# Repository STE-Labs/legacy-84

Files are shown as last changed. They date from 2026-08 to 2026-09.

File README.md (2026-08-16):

# STE-Labs Legacy 84 Vacuum Tube Amplifier Kits

## Table of Contents
- [Overview](#overview)
- [Simplified Circuit Overview](#simplified-circuit-overview)
- [Features](#features)
- [PCB Specifications](#pcb-specifications)
- [Enclosure Designs](#enclosure-designs)
- [Legacy 84 Mono](#legacy-84-mono)
- [Legacy 84 Mono-Inverted](#legacy-84-mono-inverted)
- [Legacy 84 Stereo](#legacy-84-stereo)
- [Legacy 84 Stereo-Inverted](#legacy-84-stereo-inverted)

## Overview
The Legacy 84 is a series of custom vacuum tube amplifier kits that are available in different configurations. Each configuration is designed to fit into a specific Modushop enclosure. We offer both mono and stereo configurations, with and without inverted tube sockets to enable a wide range of options for builders.

Our kits are designed for enthusiasts who want to build their own high-quality vacuum tube amplifiers. We have optimized our kits against external noise and radiation to ensure the best possible sound quality. Our designs are also optimized for ease of assembly and maintenance. We use high-quality components and materials to ensure durability and reliability.

Special care is taken into the design and routing to ensure that each trace is identical in length and width to maintain signal integrity and reduce noise.

## Simplified Circuit Overview
The Legacy 84 is a fully balanced amplifier design that uses two vacuum tubes for the input stage and two vacuum tubes for the output stage. The input stage is a SRPP/Long Tail Pair configuration, and the output stage is a push-pull configuration. The amplifier is optimized to operate without Global Negative Feedback. Local feedback (cathode degeneration) is used in the input stage to control the gain and reduce distortion. The output stage can be configured with Auto-BIAS or Fixed BIAS.

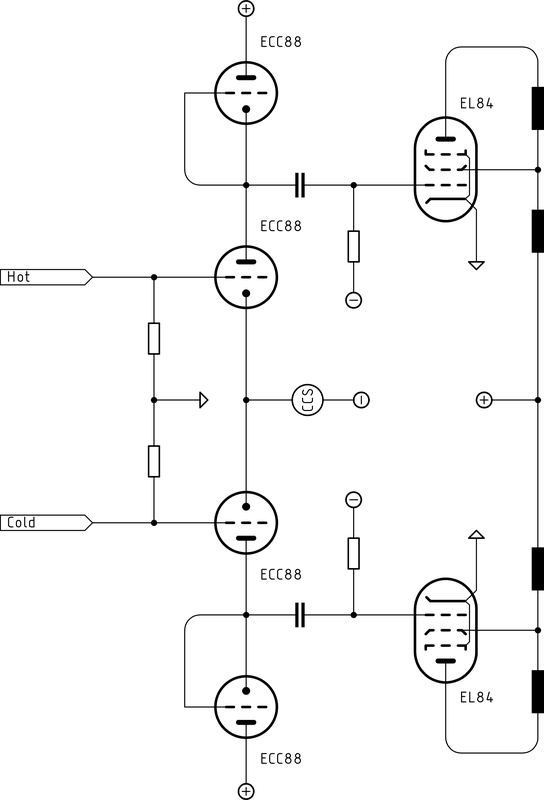
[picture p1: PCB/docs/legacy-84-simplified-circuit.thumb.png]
Legacy 84 Simplified Circuit


|Stage|Compatible Vacuum Tubes|
|---|---|
|Input Stage|6DJ8, E88CC, ECC88, PCC88, 6CG7|
|Output Stage|6BQ5, EL84, EL86|

## Features
- Fully balanced design with support for RCA and XLR inputs
- SRPP/Long Tail Pair input stage
- Push-pull output stage
- Optimized for operation without Global Negative Feedback
- Local feedback (cathode degeneration) in input stage
- Local feedback is switchable between 0dB and 4dB to reduce gain and reduce distortion even further
- Output stage can be configured with Auto-BIAS or Fixed BIAS
- Four Layer PCB Design with integrated RFI/EMI shielding
- Hybrid grounding with star-ground and dedicated ground planes
- "Twisted" trunks for heater connections to reduce electromagnetic interference
- Silicon Carbide (SiC) Rectifier for ultra low noise operation
- Through-hole components for reliability and ease of assembly. No SMD parts are used in our kits.

## PCB Specifications
We provide PCB Kits with the highest possible manufacturing standards. Our Kits are designed to fully comply with regulatory requirements and international safety standards. Our PCBs are manufactured with the thickest possible size and finished with immersion gold (ENIG) to ensure maximum durability and stability.

|Specification|Selection|
|---|---|
|Material|FR4 S1000-2M TG170|
|Thickness|2.4mm|
|Copper Weight (outer layers)|2oz|
|Copper Weight (inner layers)|1oz|
|Solder Mask|Matte black|
|Silkscreen|White|
|Finish|Immersion gold (ENIG)|

## Enclosure Designs
We have pre-designed enclosures for the Legacy 84 kits to make building easier and more accessible. These enclosures are available in different sizes and configurations to suit different needs. You can use our examples directly for your order with Modushop or you can use Front Panel Designer to customize the panels to your own taste.

### Mono Amplifiers
[Modushop Galaxy 2U GX283 & GX288](./Chassis/Galaxy/230/2U/README.md)  
[Modushop Galaxy 3U GX285](./Chassis/Galaxy/230/3U/README.md)  
[Modushop Galaxy 4U GX285](./Chassis/Galaxy/230/4U/README.md)  

### Stereo Amplifiers
[Modushop Slim Line 2U](./Chassis/Slimline/2U/README.md)  
[Modushop Slim Line 3U](./Chassis/Slimline/3U/README.md)  
[Modushop Slim Line 4U](./Chassis/Slimline/4U/README.md)  

[Modushop Galaxy 2U GX383 & GX388](./Chassis/Galaxy/330/2U/README.md)  
[Modushop Galaxy 3U GX385](./Chassis/Galaxy/330/3U/README.md)  
[Modushop Galaxy 4U GX385](./Chassis/Galaxy/330/4U/README.md)  

## Legacy 84 Mono
[View Details](./legacy-84-mono/README.md)

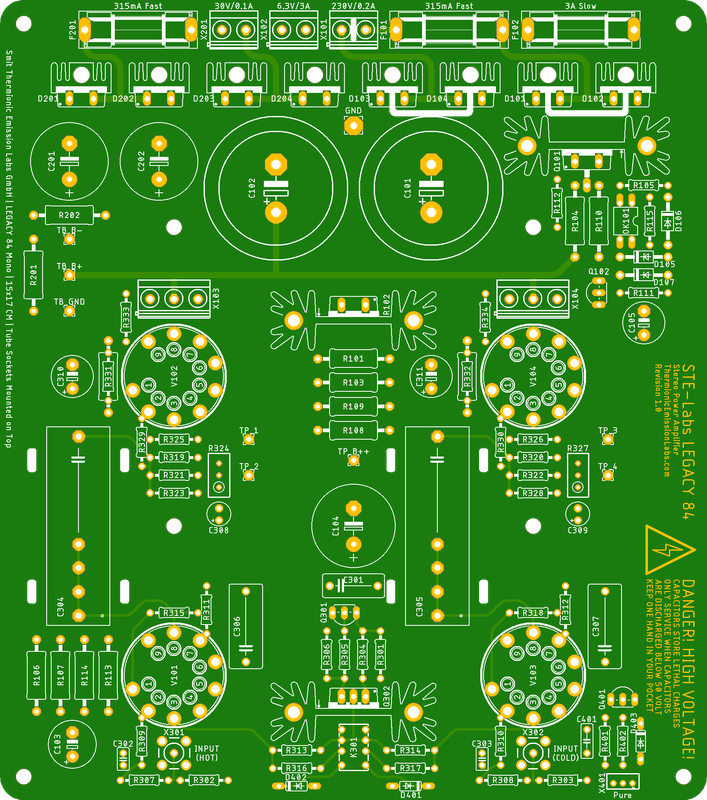
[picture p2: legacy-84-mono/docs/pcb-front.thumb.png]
Legacy 84 Mono


|Dimension|Size|
|---|---|
|Width|150 MM|
|Height|2.4 MM|
|Depth|170 MM|

|Enclosure|
|---|
|[Modushop Galaxy 3U GX285](../Chassis/Galaxy/230/3U/README.md)|
|[Modushop Galaxy 4U GX285](../Chassis/Galaxy/230/4U/README.md)|

## Legacy 84 Mono-Inverted
[View Details](./legacy-84-mono-inverted/README.md)

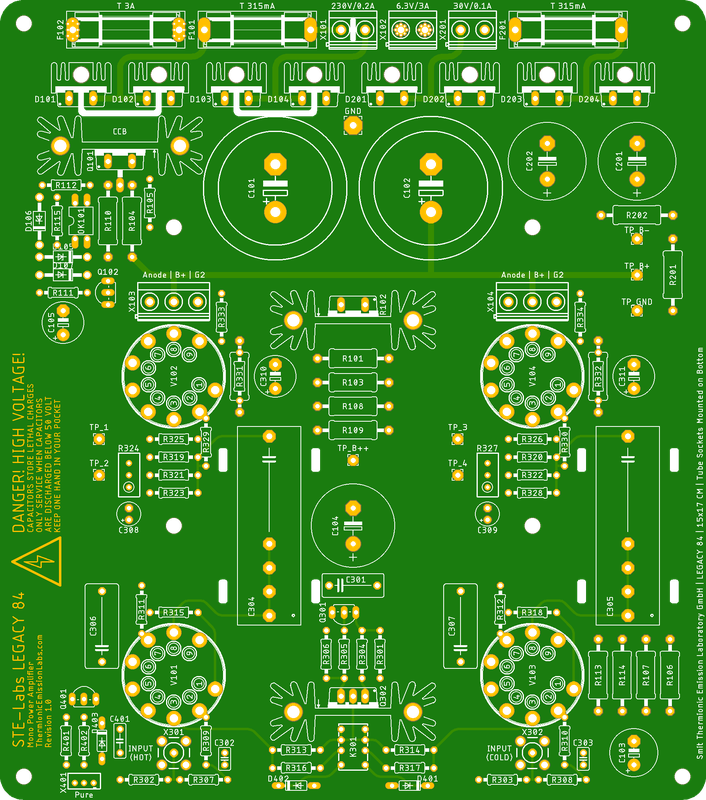
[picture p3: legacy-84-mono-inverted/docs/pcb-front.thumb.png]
Legacy 84 Mono-Inverted


|Dimension|Size|
|---|---|
|Width|170 MM|
|Height|2.4 MM|
|Depth|150 MM|

|Enclosure|
|---|
|[Modushop Galaxy 2U GX283 & GX288](../Chassis/Galaxy/230/2U/README.md)|
|[Modushop Slim Line 2U](../Chassis/Slimline/2U/README.md)|

## Legacy 84 Stereo
[View Details](./legacy-84-stereo/README.md)

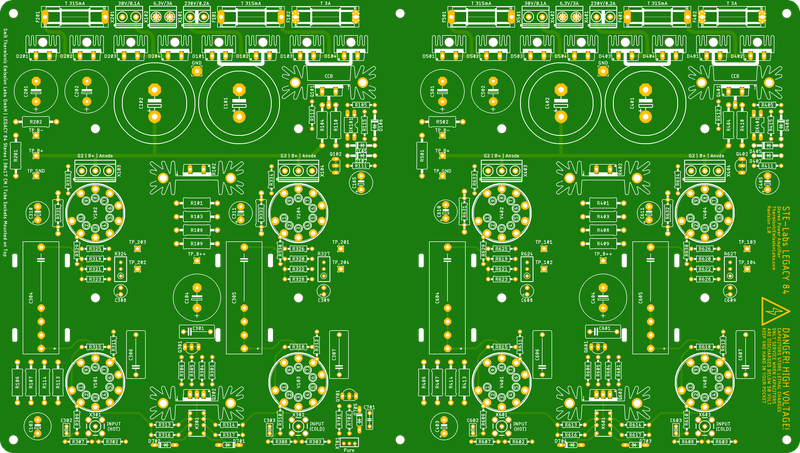
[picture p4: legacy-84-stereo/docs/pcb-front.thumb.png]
Legacy 84 Stereo


|Dimension|Size|
|---|---|
|Width|300 MM|
|Height|2.4 MM|
|Depth|170 MM|

|Enclosure|
|---|
|[Modushop Galaxy 3U GX385](../Chassis/Galaxy/330/3U/README.md)|
|[Modushop Galaxy 4U GX385](../Chassis/Galaxy/330/4U/README.md)|
|[Modushop Slim Line 3U](../Chassis/Slimline/3U/README.md)|
|[Modushop Slim Line 4U](../Chassis/Slimline/4U/README.md)|

## Legacy 84 Stereo-Inverted
[View Details](./legacy-84-stereo-inverted/README.md)

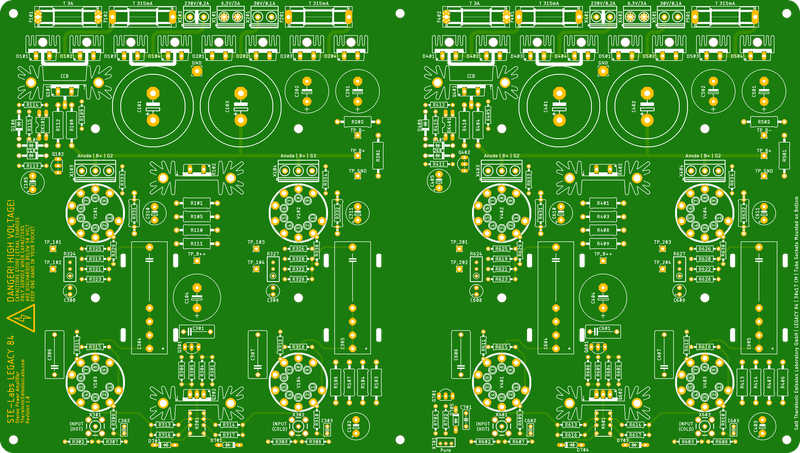
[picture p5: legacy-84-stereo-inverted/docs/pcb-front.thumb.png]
Legacy 84 Stereo-Inverted


|Dimension|Size|
|---|---|
|Width|300 MM|
|Height|2.4 MM|
|Depth|150 MM|

|Enclosure|
|---|
|[Modushop Galaxy 2U GX383 & GX388](../Chassis/Galaxy/330/2U/README.md)|

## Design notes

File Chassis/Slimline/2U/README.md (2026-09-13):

# Modushop Slim Line 2U
These are custom drawings for the **Modushop Slim Line 2U** amplifier enclosures. 
The panel designs are perfectly tailored to fit two of the **Legacy 84 Mono Inverted PCB Kits**.

|Model|Size|Link|PCB|
|-----|----|----|---|
|[Slim Line 02/230 Silver](https://modushop.biz/site/index.php?route=product/product&path=120_246_249&product_id=99)|435 x 230 MM 2U|[https://modushop.biz/site/index.php?route=product/product&path=120_246_249&product_id=97](https://modushop.biz/site/index.php?route=product/product&path=120_246_249&product_id=97)|Legacy 84 Mono Inverted|
|[Slim Line 02/230 Black](https://modushop.biz/site/index.php?route=product/product&path=120_246_249&product_id=100)|435 x 230 MM 2U|[https://modushop.biz/site/index.php?route=product/product&path=120_246_249&product_id=98](https://modushop.biz/site/index.php?route=product/product&path=120_246_249&product_id=98)|Legacy 84 Mono Inverted|
|[Slim Line 02/280 Silver](https://modushop.biz/site/index.php?route=product/product&path=120_246_249&product_id=101)|435 x 280 MM 2U|[https://modushop.biz/site/index.php?route=product/product&path=120_246_249&product_id=99](https://modushop.biz/site/index.php?route=product/product&path=120_246_249&product_id=99)|Legacy 84 Mono Inverted|
|[Slim Line 02/280 Black](https://modushop.biz/site/index.php?route=product/product&path=120_246_249&product_id=102)|435 x 280 MM 2U|[https://modushop.biz/site/index.php?route=product/product&path=120_246_249&product_id=100](https://modushop.biz/site/index.php?route=product/product&path=120_246_249&product_id=100)|Legacy 84 Mono Inverted|

Available at [Modushop.biz](https://modushop.biz/)

## Table of Contents
[Home](../../../README.md)
- [Legacy 84 Mono Inverted](#legacy-84-mono-inverted)
- [Common Panels](#common-panels)
- [Slim Line 02/230](#slim-line-02230)
- [Slim Line 02/280](#slim-line-02280)
- [Additional Kits and Components](#additional-kits-and-components)

## Legacy 84 Mono Inverted
Legacy 84 Mono Inverted PCB Kit

## Common Panels
[Top](#modushop-slim-line-2u)  

### Table of Contents
- [Front Panel](#front-panel)
- [Rear Panel RCA](#rear-panel-rca)
- [Rear Panel XLR](#rear-panel-xlr)

### Front Panel
Modushop Slim Line 2U Front Panel  

### Rear Panel RCA
Modushop Slim Line 2U Rear Panel RCA

### Rear Panel XLR
Modushop Slim Line 2U Rear Panel XLR

## Slim Line 02/230

[Top](#modushop-slim-line-2u)  

### Table of Contents
- [Top Panel](#top-panel-02230)
- [Bottom Panel](#bottom-panel-02230)

### Specifications
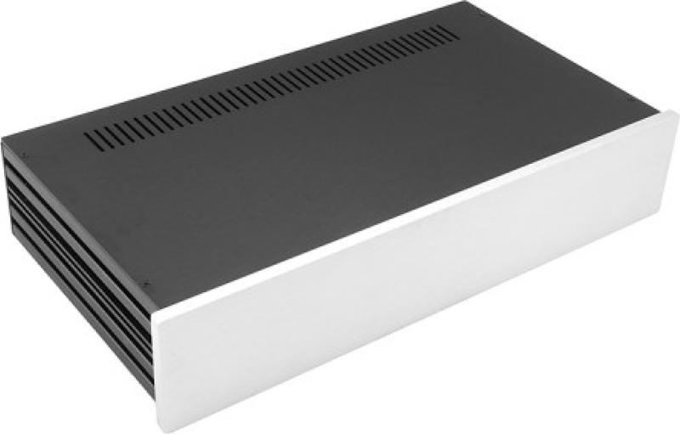
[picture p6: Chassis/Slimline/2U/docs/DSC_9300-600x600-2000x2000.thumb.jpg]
Modushop Slim Line 02/230

|Dimension|Height|Width|Depth|
|---|---|---|---|
|Internal|80|415|230|
|External|86|435|243|
|Faceplate|90|450|10|
|Side Panels|10mm side panels black anodized aluminum|
|Top Cover|3mm black anodized aluminum|
|Bottom Cover|3mm black anodized aluminum|
|Front Panel|10mm black/silver anodized aluminum|
|Rear Panel|3mm black/silver anodized aluminum|

### Top Panel 02/230
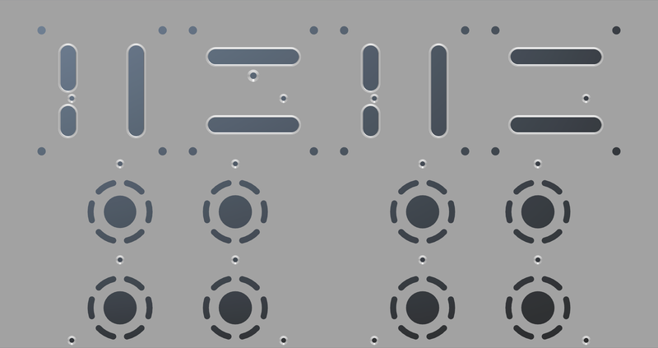
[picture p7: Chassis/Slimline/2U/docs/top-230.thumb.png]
Modushop Slim Line 02/230 Top Panel


### Bottom Panel 02/230
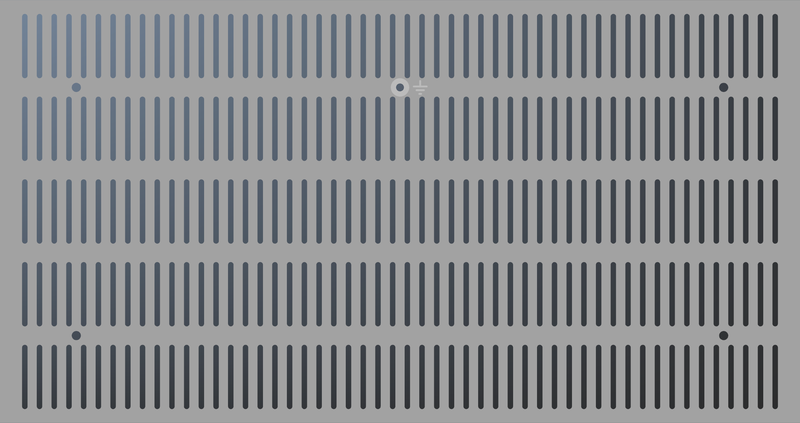
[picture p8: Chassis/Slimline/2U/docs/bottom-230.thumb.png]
Modushop Slim Line 02/230 Bottom Panel


## Slim Line 02/280

[Top](#modushop-slim-line-2u)  

### Table of Contents
- [Top Panel](#top-panel-02280)
- [Bottom Panel](#bottom-panel-02280)

### Specifications
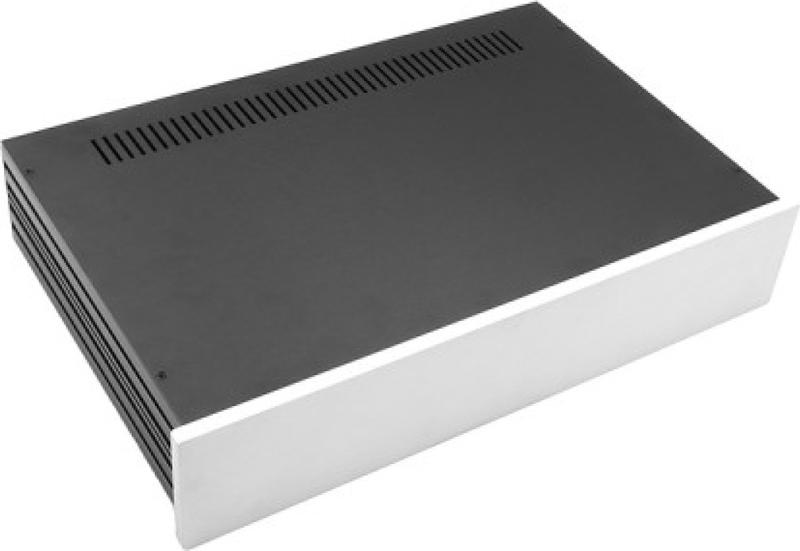
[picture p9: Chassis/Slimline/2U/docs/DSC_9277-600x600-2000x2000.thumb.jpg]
Modushop Slim Line 02/280

|Dimension|Height|Width|Depth|
|---|---|---|---|
|Internal|80|415|280|
|External|86|435|293|
|Faceplate|90|450|10|
|Side Panels|10mm side panels black anodized aluminum|
|Top Cover|3mm black anodized aluminum|
|Bottom Cover|3mm black anodized aluminum|
|Front Panel|10mm black/silver anodized aluminum|
|Rear Panel|3mm black/silver anodized aluminum|

### Top Panel 02/280
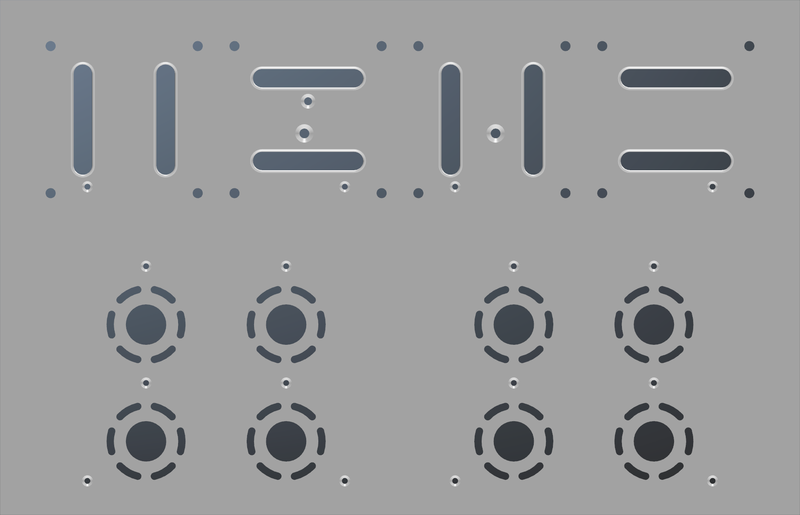
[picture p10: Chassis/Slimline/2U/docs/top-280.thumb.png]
Modushop Slim Line 02/280 Top Panel


### Bottom Panel 02/280
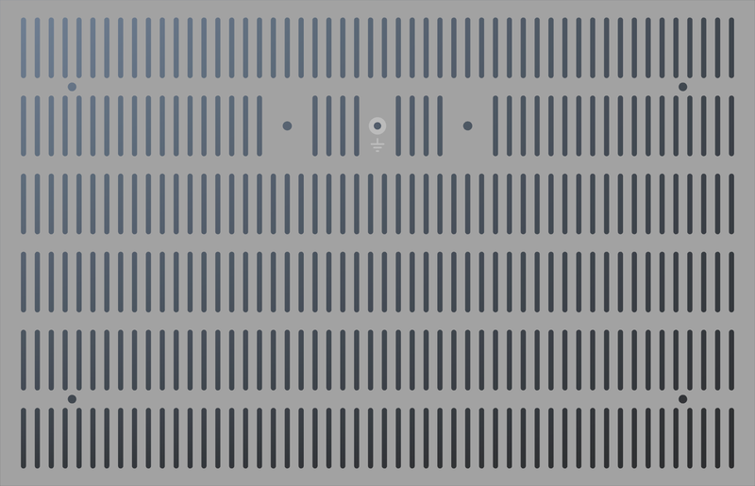
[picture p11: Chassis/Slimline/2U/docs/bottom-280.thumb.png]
Modushop Slim Line 02/280 Bottom Panel


## Additional Kits and Components
[Top](#modushop-slim-line-2u)  

|Item|Description|Product Link|
|----|----|----|
|Legacy 84 Mono Inverted|Legacy 84 Mono Inverted Kit|[Legacy 84 Mono Inverted Kit](../../README.md#legacy-84-mono-inverted)|
|Standby Power Supply|Standby Power Supply Kit|[../../README.md#standby-power-supply](../../README.md#standby-power-supply)|
|IO Shield 2U 6.2 RCA|IO Shield 2U 6.2 RCA|[https://github.com/STE-Labs/io-boards/tree/main/io-board-6-2-rca/README.md](https://github.com/STE-Labs/io-boards/tree/main/io-board-6-2-rca/README.md)|
|IO Shield 2U 6.2 XLR|IO Shield 2U 6.2 XLR|[https://github.com/STE-Labs/io-boards/tree/main/io-board-6-2-xlr/README.md](https://github.com/STE-Labs/io-boards/tree/main/io-board-6-2-xlr/README.md)|
|Anti Vandal Switch|Anti Vandal Switch 16MM with LED|[../../README.md#anti-vandal-switch](../../README.md#anti-vandal-switch)|
|Aluminum Knob 25mm|Aluminum Knob 25mm|[https://modushop.biz/site/index.php?route=product/product&path=312&product_id=755](https://modushop.biz/site/index.php?route=product/product&path=312&product_id=755)|
|Aluminum Knob 40mm|Aluminum Knob 40mm|[https://modushop.biz/site/index.php?route=product/product&path=312&product_id=757](https://modushop.biz/site/index.php?route=product/product&path=312&product_id=757)|
|ECC88|ECC88 Dual Triode|[https://www.jj-electronic.com/en/e88cc-6922-6dj8](https://www.jj-electronic.com/en/e88cc-6922-6dj8)|
|EL84|EL84 Output Pentode|[https://www.jj-electronic.com/en/el84-6bq5](https://www.jj-electronic.com/en/el84-6bq5)|

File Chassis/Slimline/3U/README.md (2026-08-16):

# Modushop Slim Line 3U
Drawings for Custom Amplifier Enclosures

## Table of Contents
[Home](../../../README.md)
- [Common Panels](#common-panels)
- [Slim Line 03/280](#slim-line-03280)
- [Slim Line 03/350](#slim-line-03350)

## Common Panels

[Top](#modushop-slim-line-3u)  

### Table of Contents
- [Front Panel](#front-panel)
- [Rear Panel RCA](#rear-panel-rca)
- [Rear Panel XLR](#rear-panel-xlr)

### Front Panel
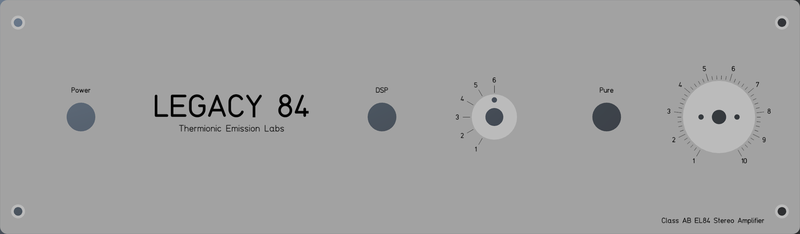
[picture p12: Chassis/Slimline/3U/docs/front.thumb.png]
Modushop Slim Line 2U Front Panel


### Rear Panel RCA
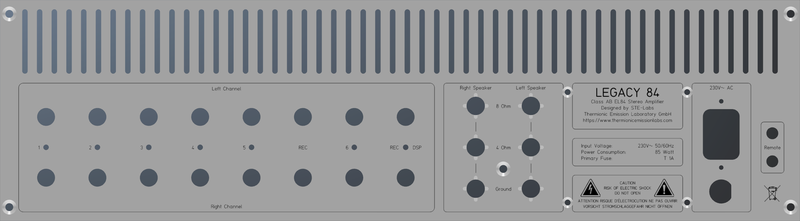
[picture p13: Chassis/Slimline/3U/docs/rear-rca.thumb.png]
Modushop Slim Line 2U Rear Panel RCA


### Rear Panel XLR
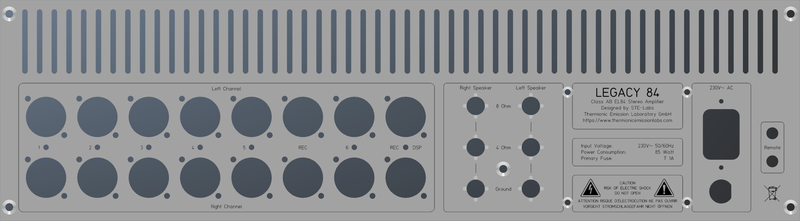
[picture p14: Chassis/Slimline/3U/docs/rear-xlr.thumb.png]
Modushop Slim Line 2U Rear Panel XLR


## Slim Line 03/280

[Top](#modushop-slim-line-3u)  

### Table of Contents
- [Top Panel](#top-panel-03280)
- [Bottom Panel](#bottom-panel-03280)

### Specifications
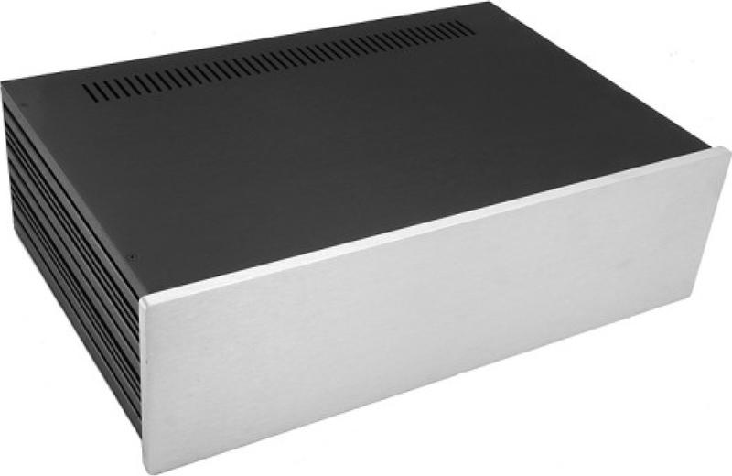
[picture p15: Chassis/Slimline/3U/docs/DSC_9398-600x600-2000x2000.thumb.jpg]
Modushop Slim Line 03/280

|Dimension|Height|Width|Depth|
|---|---|---|---|
|Internal|120|415|280|
|External|126|435|293|
|Faceplate|130|450|10|
|Side Panels|10mm side panels black anodized aluminum|
|Top Cover|3mm black anodized aluminum|
|Bottom Cover|3mm black anodized aluminum|
|Front Panel|10mm black/silver anodized aluminum|
|Rear Panel|3mm black/silver anodized aluminum|

### Top Panel 03/280
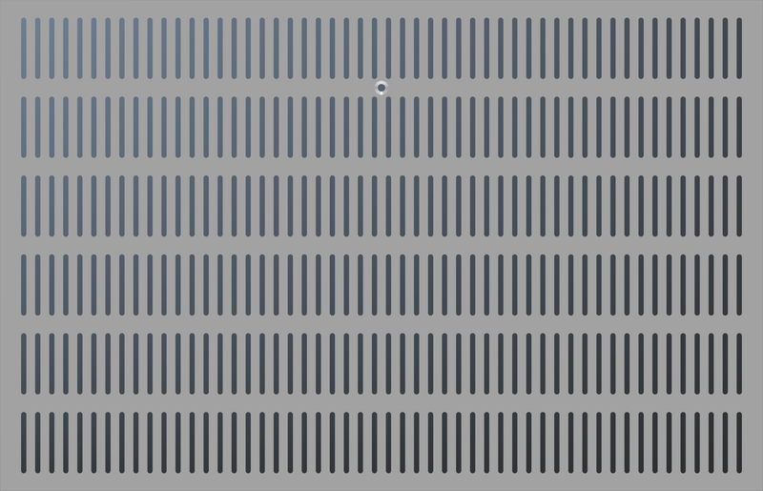
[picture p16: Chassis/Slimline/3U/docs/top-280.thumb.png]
Modushop Slim Line 03/280 Top Panel


### Bottom Panel 03/280
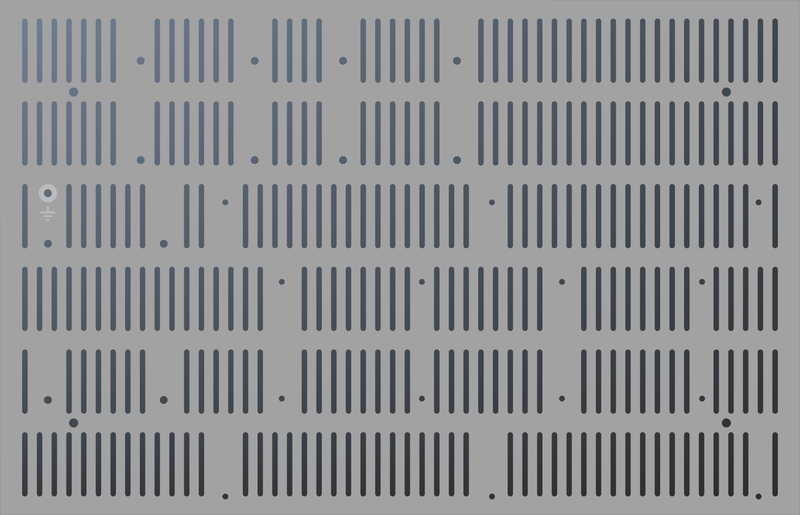
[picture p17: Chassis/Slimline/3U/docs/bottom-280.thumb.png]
Modushop Slim Line 03/280 Bottom Panel


## Slim Line 03/350

[Top](#modushop-slim-line-3u)  

### Table of Contents
- [Top Panel](#top-panel-03350)
- [Bottom Panel](#bottom-panel-03350)

### Specifications
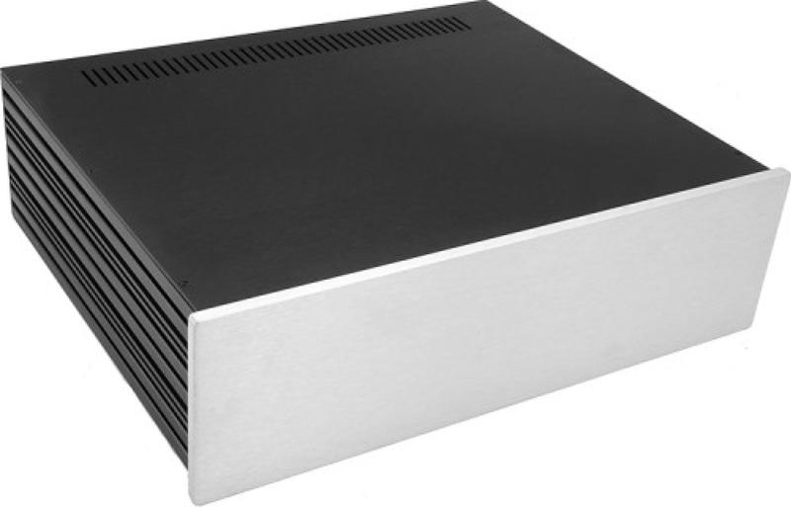
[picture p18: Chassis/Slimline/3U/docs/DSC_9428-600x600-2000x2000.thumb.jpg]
Modushop Slim Line 03/350

|Dimension|Height|Width|Depth|
|---|---|---|---|
|Internal|120|415|350|
|External|126|435|363|
|Faceplate|130|450|10|
|Side Panels|10mm side panels black anodized aluminum|
|Top Cover|3mm black anodized aluminum|
|Bottom Cover|3mm black anodized aluminum|
|Front Panel|10mm black/silver anodized aluminum|
|Rear Panel|3mm black/silver anodized aluminum|

### Top Panel 03/350
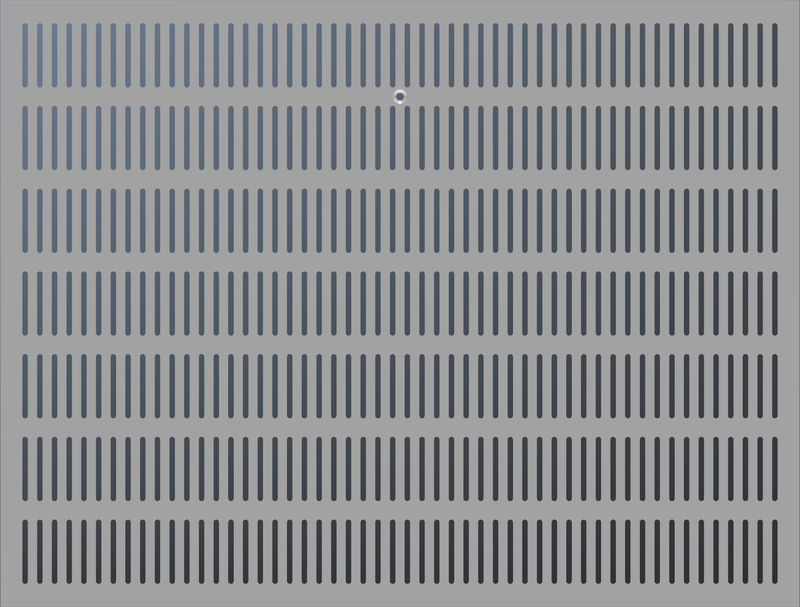
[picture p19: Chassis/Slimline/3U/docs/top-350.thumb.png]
Modushop Slim Line 03/350 Top Panel


### Bottom Panel 03/350
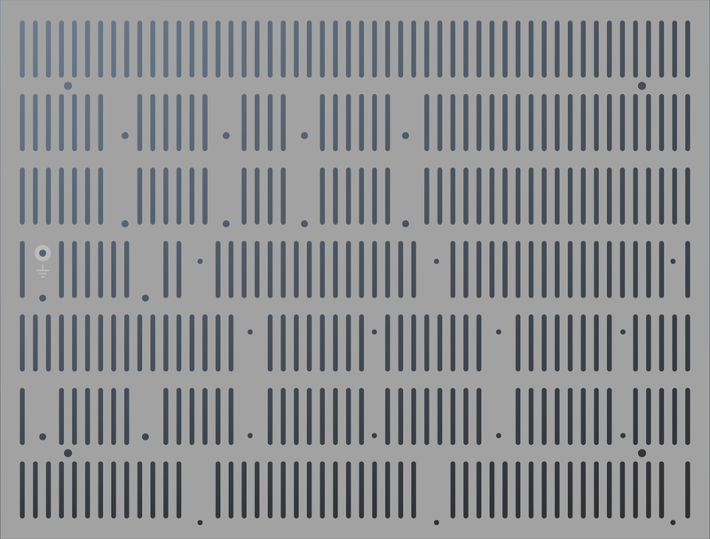
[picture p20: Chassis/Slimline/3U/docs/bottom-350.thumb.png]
Modushop Slim Line 03/350 Bottom Panel


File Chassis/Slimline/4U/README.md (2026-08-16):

# Modushop Slim Line 4U
Drawings for Custom Amplifier Enclosures

## Table of Contents
[Home](../../../README.md)
- [Common Panels](#common-panels)
- [Slim Line 04/280](#slim-line-04280)
- [Slim Line 04/350](#slim-line-04350)

## Common Panels

[Top](#modushop-slim-line-4u)  

### Table of Contents
- [Front Panel](#front-panel)
- [Rear Panel RCA](#rear-panel-rca)
- [Rear Panel XLR](#rear-panel-xlr)

### Front Panel
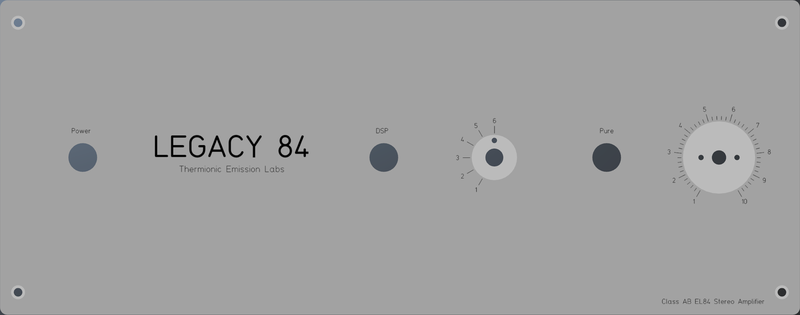
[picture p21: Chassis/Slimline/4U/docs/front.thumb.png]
Modushop Slim Line 2U Front Panel


### Rear Panel RCA
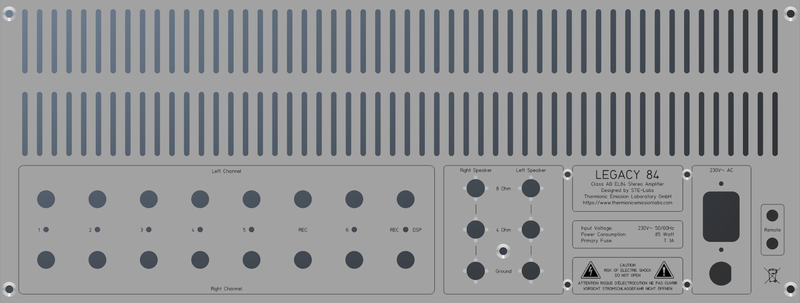
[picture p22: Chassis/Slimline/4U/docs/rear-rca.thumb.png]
Modushop Slim Line 2U Rear Panel RCA


### Rear Panel XLR
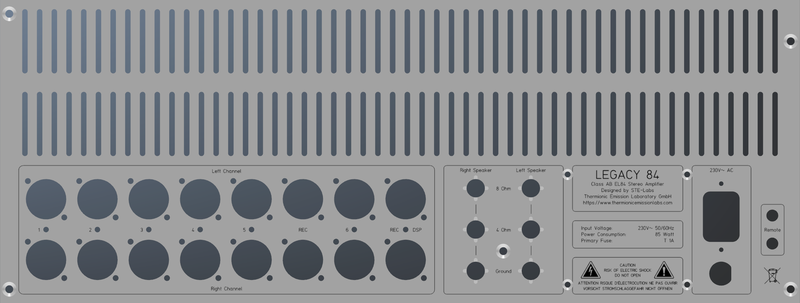
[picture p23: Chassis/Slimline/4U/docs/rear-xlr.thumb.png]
Modushop Slim Line 2U Rear Panel XLR


## Slim Line 04/280

[Top](#modushop-slim-line-4u)  

### Table of Contents
- [Top Panel](#top-panel-04280)
- [Bottom Panel](#bottom-panel-04280)

### Specifications
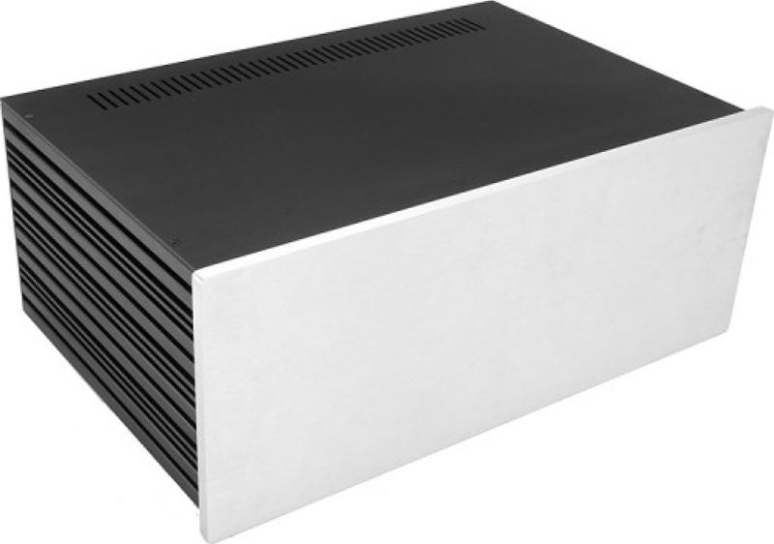
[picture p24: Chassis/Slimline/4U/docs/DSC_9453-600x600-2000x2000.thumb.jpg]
Modushop Slim Line 04/280

|Dimension|Height|Width|Depth|
|---|---|---|---|
|Internal|120|415|280|
|External|126|435|293|
|Faceplate|130|450|10|
|Side Panels|10mm side panels black anodized aluminum|
|Top Cover|3mm black anodized aluminum|
|Bottom Cover|3mm black anodized aluminum|
|Front Panel|10mm black/silver anodized aluminum|
|Rear Panel|3mm black/silver anodized aluminum|

### Top Panel 04/280
Modushop Slim Line 04/280 Top Panel

### Bottom Panel 04/280
Modushop Slim Line 04/280 Bottom Panel

## Slim Line 04/350

[Top](#modushop-slim-line-4u)  

### Table of Contents
- [Top Panel](#top-panel-04350)
- [Bottom Panel](#bottom-panel-04350)

### Specifications
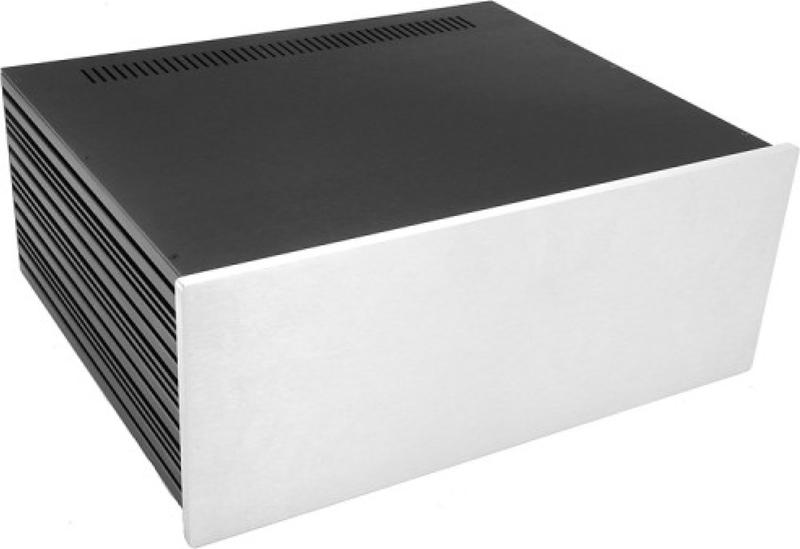
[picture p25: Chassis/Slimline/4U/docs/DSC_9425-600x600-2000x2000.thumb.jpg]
Modushop Slim Line 04/350

|Dimension|Height|Width|Depth|
|---|---|---|---|
|Internal|120|415|350|
|External|126|435|363|
|Faceplate|130|450|10|
|Side Panels|10mm side panels black anodized aluminum|
|Top Cover|3mm black anodized aluminum|
|Bottom Cover|3mm black anodized aluminum|
|Front Panel|10mm black/silver anodized aluminum|
|Rear Panel|3mm black/silver anodized aluminum|

### Top Panel 04/350
Modushop Slim Line 04/350 Top Panel

### Bottom Panel 04/350
Modushop Slim Line 04/350 Bottom Panel

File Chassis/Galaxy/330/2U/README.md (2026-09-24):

# Modushop Galaxy GX383
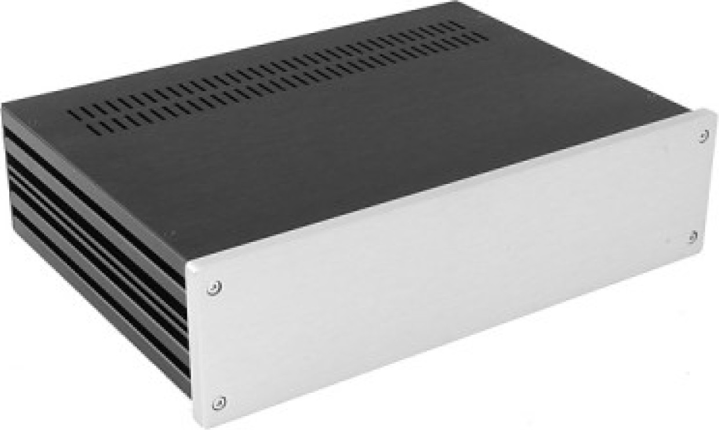
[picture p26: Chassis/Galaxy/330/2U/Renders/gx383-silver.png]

Size: 330 x 230 mm with 10mm front panel

Chose your project
|Name|Description|Inputs|Outputs|
|---|---|---|---|
|[GX383-3-1](./GX383-3-1/README.md)|Drawings for the GX383 with RCA connectors|3|1|
|[GX383-4-0](./GX383-4-0/README.md)|Drawings for the GX383 with RCA connectors|4|0|
|[GX383-4-1](./GX383-4-1/README.md)|Drawings for the GX383 with RCA connectors|4|1|
|[GX383-5-0](./GX383-5-0/README.md)|Drawings for the GX383 with RCA connectors|5|0|

# Modushop Galaxy GX388
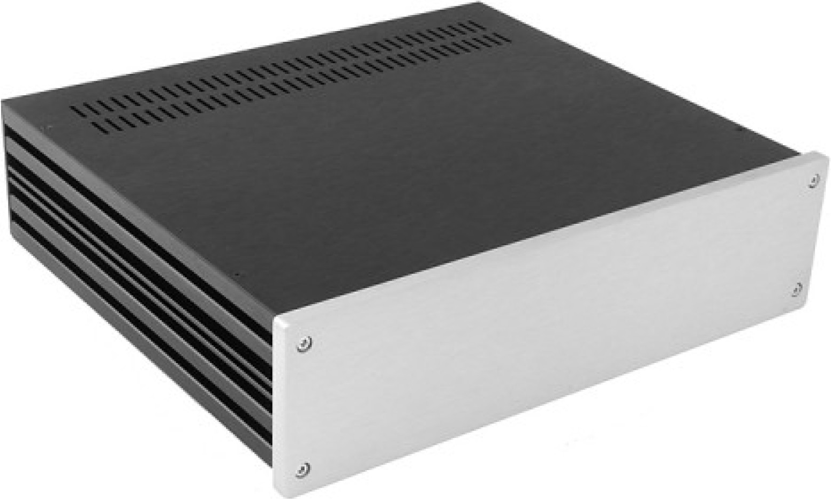
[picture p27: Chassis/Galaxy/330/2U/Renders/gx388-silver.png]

Size: 330 x 280 mm with 10mm front panel

Chose your project
|Name|Description|Inputs|Outputs|
|---|---|---|---|
|[GX388-3-1](./GX388-3-1/README.md)|Drawings for the GX388 with RCA connectors|3|1|
|[GX388-4-0](./GX388-4-0/README.md)|Drawings for the GX388 with RCA connectors|4|0|
|[GX388-4-1](./GX388-4-1/README.md)|Drawings for the GX388 with RCA connectors|4|1|
|[GX388-5-0](./GX388-5-0/README.md)|Drawings for the GX388 with RCA connectors|5|0|

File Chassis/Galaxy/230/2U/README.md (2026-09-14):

# Modushop Galaxy 230 2U
[Home](../../../README.md)

These are custom drawings for the **Modushop Galaxy 2U** amplifier enclosures. 
The panel designs are perfectly tailored to fit the **Legacy 84 Mono Inverted PCB Kit**.

|Model|Size|Link|PCB|
|-----|----|----|---|
|[Galaxy 2U GX283 Silver](https://modushop.biz/site/index.php?route=product/product&path=25_291_293&product_id=439)|230 x 230 MM 2U|[https://modushop.biz/site/index.php?route=product/product&path=25_291_293&product_id=439](https://modushop.biz/site/index.php?route=product/product&path=25_291_293&product_id=439)|Legacy 84 Mono Inverted|
|[Galaxy 2U GX283 Black](https://modushop.biz/site/index.php?route=product/product&path=25_291_293&product_id=440)|230 x 230 MM 2U|[https://modushop.biz/site/index.php?route=product/product&path=25_291_293&product_id=440](https://modushop.biz/site/index.php?route=product/product&path=25_291_293&product_id=440)|Legacy 84 Mono Inverted|
|[Galaxy 2U GX288 Silver](https://modushop.biz/site/index.php?route=product/product&path=25_291_293&product_id=443)|230 x 280 MM 2U|[https://modushop.biz/site/index.php?route=product/product&path=25_291_293&product_id=443](https://modushop.biz/site/index.php?route=product/product&path=25_291_293&product_id=443)|Legacy 84 Mono Inverted|
|[Galaxy 2U GX288 Black](https://modushop.biz/site/index.php?route=product/product&path=25_291_293&product_id=444)|230 x 280 MM 2U|[https://modushop.biz/site/index.php?route=product/product&path=25_291_293&product_id=444](https://modushop.biz/site/index.php?route=product/product&path=25_291_293&product_id=444)|Legacy 84 Mono Inverted|

Available at [Modushop.biz](https://modushop.biz/)

## Table of Contents
- [Legacy 84 Mono Inverted](#legacy-84-mono-inverted)
- [Common Panels](#common-panels)
- [Galaxy GX283](#galaxy-gx283)
- [Galaxy GX288](#galaxy-gx288)

## Legacy 84 Mono Inverted
Legacy 84 Mono Inverted PCB Kit

## Common Panels
[Top](#modushop-galaxy-230-2u)  
These panels are shared between all Galaxy 2U models.

#### Front Panel
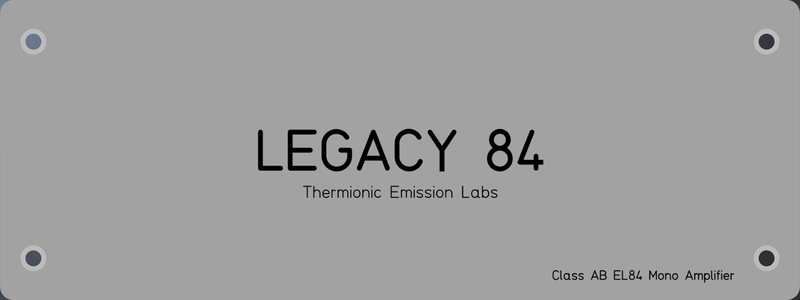
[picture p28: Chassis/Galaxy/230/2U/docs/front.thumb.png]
Modushop Galaxy 2U Front Panel


#### Rear Panel RCA
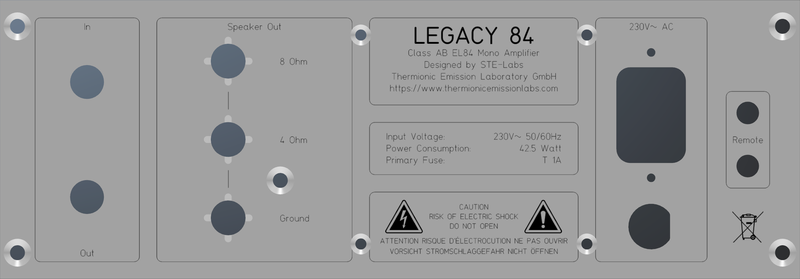
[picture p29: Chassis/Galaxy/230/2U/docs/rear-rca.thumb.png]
Modushop Galaxy 2U Rear Panel


#### Rear Panel XLR
Modushop Galaxy 2U Rear Panel

## Galaxy GX283
[Top](#modushop-galaxy-230-2u)

### Table of Contents
- [Top Panel](#top-panel-gx283)
- [Bottom Panel](#bottom-panel-gx283)

### Specifications
Galaxy GX283

### Top Panel GX283
Modushop Galaxy GX283 Top Panel

### Bottom Panel GX283
Modushop Galaxy GX283 Bottom Panel

## Galaxy GX288
[Top](#modushop-galaxy-230-2u)

### Table of Contents
- [Top Panel](#top-panel-gx288)
- [Bottom Panel](#bottom-panel-gx288)

### Specifications
Galaxy GX288

### Top Panel GX288
Modushop Galaxy GX288 Top Panel

### Bottom Panel GX288
Modushop Galaxy GX288 Bottom Panel

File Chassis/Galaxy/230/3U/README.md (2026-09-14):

# Modushop Galaxy 230 3U
[Home](../../../README.md)  

These are custom drawings for the **Modushop Galaxy 3U** amplifier enclosures. 
The panel designs are perfectly tailored to fit the **Legacy 84 Mono PCB Kit**.

|Model|Size|Link|PCB|
|-----|----|----|---|
|[Galaxy 3U GX288 Silver](https://modushop.biz/site/index.php?route=product/product&path=30_295_298&product_id=632)|230 x 280 MM 3U|[https://modushop.biz/site/index.php?route=product/product&path=30_295_298&product_id=632](https://modushop.biz/site/index.php?route=product/product&path=30_295_298&product_id=632)|Legacy 84 Mono|
|[Galaxy 3U GX288 Black](https://modushop.biz/site/index.php?route=product/product&path=30_295_298&product_id=633)|230 x 280 MM 3U|[https://modushop.biz/site/index.php?route=product/product&path=30_295_298&product_id=633](https://modushop.biz/site/index.php?route=product/product&path=30_295_298&product_id=633)|Legacy 84 Mono|
|[Galaxy 3U GX285 Silver](https://modushop.biz/site/index.php?route=product/product&path=30_295_298&product_id=628)|230 x 350 MM 3U|[https://modushop.biz/site/index.php?route=product/product&path=30_295_298&product_id=628](https://modushop.biz/site/index.php?route=product/product&path=30_295_298&product_id=628)|Legacy 84 Mono|
|[Galaxy 3U GX285 Black](https://modushop.biz/site/index.php?route=product/product&path=30_295_298&product_id=629)|230 x 350 MM 3U|[https://modushop.biz/site/index.php?route=product/product&path=30_295_298&product_id=629](https://modushop.biz/site/index.php?route=product/product&path=30_295_298&product_id=629)|Legacy 84 Mono|

Available at [Modushop.biz](https://modushop.biz/)

## Table of Contents
- [Legacy 84 Mono](#legacy-84-mono)
- [Common Panels](#common-panels)
- [Galaxy GX288](#galaxy-gx288)
- [Galaxy GX285](#galaxy-gx285)

## Legacy 84 Mono
Legacy 84 Mono PCB Kit

## Common Panels
[Top](#modushop-galaxy-330-3u)  
These panels are shared between all Galaxy 3U models.

#### Front Panel
Modushop Galaxy 2U Front Panel

#### Rear Panel RCA
Modushop Galaxy 2U Rear Panel RCA

#### Rear Panel XLR
Modushop Galaxy 2U Rear Panel XLR

## Galaxy GX288
[Top](#modushop-galaxy-330-3u)  

### Table of Contents
- [Top Panel](#top-panel-gx288)
- [Bottom Panel](#bottom-panel-gx288)

### Specifications
Galaxy GX288

### Top Panel GX288
Modushop Galaxy GX288 Top Panel

### Bottom Panel GX288
Modushop Galaxy GX288 Bottom Panel

## Galaxy GX285
[Top](#modushop-galaxy-330-3u)  

### Table of Contents
- [Top Panel](#top-panel-gx285)
- [Bottom Panel](#bottom-panel-gx285)

### Specifications
Galaxy GX285

### Top Panel GX285
Modushop Galaxy GX285 Top Panel

### Bottom Panel GX285
Modushop Galaxy GX285 Bottom Panel

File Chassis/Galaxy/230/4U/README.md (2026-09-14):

# Modushop Galaxy 230 4U
[Home](../../../README.md)  

These are custom drawings for the **Modushop Galaxy 4U** amplifier enclosures. 
The panel designs are perfectly tailored to fit the **Legacy 84 Mono PCB Kit**.

|Model|Size|Link|PCB|
|-----|----|----|---|
|[Galaxy 4U GX288 Silver](https://modushop.biz/site/index.php?route=product/product&path=31_300_302&product_id=634)|230 x 280 MM 4U|[https://modushop.biz/site/index.php?route=product/product&path=31_300_302&product_id=634](https://modushop.biz/site/index.php?route=product/product&path=31_300_302&product_id=634)|Legacy 84 Mono|
|[Galaxy 4U GX288 Black](https://modushop.biz/site/index.php?route=product/product&path=31_300_303&product_id=635)|230 x 280 MM 4U|[https://modushop.biz/site/index.php?route=product/product&path=31_300_303&product_id=635](https://modushop.biz/site/index.php?route=product/product&path=31_300_303&product_id=635)|Legacy 84 Mono|
|[Galaxy 4U GX285 Silver](https://modushop.biz/site/index.php?route=product/product&path=31_300_302&product_id=631)|230 x 350 MM 4U|[https://modushop.biz/site/index.php?route=product/product&path=31_300_302&product_id=631](https://modushop.biz/site/index.php?route=product/product&path=31_300_302&product_id=631)|Legacy 84 Mono|
|[Galaxy 4U GX285 Black](https://modushop.biz/site/index.php?route=product/product&path=31_300_303&product_id=630)|230 x 350 MM 4U|[https://modushop.biz/site/index.php?route=product/product&path=31_300_303&product_id=630](https://modushop.biz/site/index.php?route=product/product&path=31_300_303&product_id=630)|Legacy 84 Mono|

Available at [Modushop.biz](https://modushop.biz/)

## Table of Contents
- [Legacy 84 Mono](#legacy-84-mono)
- [Common Panels](#common-panels)
- [Galaxy GX288](#galaxy-gx288)
- [Galaxy GX285](#galaxy-gx285)

## Legacy 84 Mono
Legacy 84 Mono PCB Kit

## Common Panels
[Top](#modushop-galaxy-330-4u)  
These panels are shared between all Galaxy 4U models.

#### Front Panel
Modushop Galaxy 2U Front Panel

#### Rear Panel RCA
Modushop Galaxy 2U Rear Panel

#### Rear Panel XLR
Modushop Galaxy 2U Rear Panel

## Galaxy GX288

[Top](#modushop-galaxy-330-4u)  
### Table of Contents
- [Top Panel](#top-panel-gx288)
- [Bottom Panel](#bottom-panel-gx288)

### Specifications
Galaxy GX288

### Top Panel GX288
Modushop Galaxy GX288 Top Panel

### Bottom Panel GX288
Modushop Galaxy GX288 Bottom Panel

## Galaxy GX285

[Top](#modushop-galaxy-330-4u)  

### Table of Contents
- [Top Panel](#top-panel-gx285)
- [Bottom Panel](#bottom-panel-gx285)

### Specifications
Galaxy GX285

### Top Panel GX285
Modushop Galaxy GX285 Top Panel

### Bottom Panel GX285
Modushop Galaxy GX285 Bottom Panel

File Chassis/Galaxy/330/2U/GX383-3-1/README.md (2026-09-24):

# Modushop GX383 with three inputs and one output


Here you can find an overview with the source files needed for a customized GX383 chassis from Modushop.
Use the URLs in this document to ensure that you select the proper chassis and customization options.

## Front Panel Designer Files
All the files provided here are example files that have been fully tested for compatability with the [Legacy 84](https://thermionicemissionlabs.com/products/legacy/84-stereo-inverted) and the [Impact 84]((https://thermionicemissionlabs.com/products/impact/84-stereo-inverted)). You are free to modify these drawings to your own liking. We do not provide support for these drawings, nor do we validate them if you modify them. Please notify Modushop if you have modified our drawings so they can validate your changes and ensure that they can manufacture the panels for you.

Keep these limitations in mind in modify the drawings:
- The minimum radius for a corner is 2mm
- Rounded bezels are not possible

You can download a free copy of Front Panel Designer [here](https://www.frontpanelexpress.com/front-panel-designer).

### Templates for Customized Panels
Download complete panel templates [here](https://github.com/STE-Labs/legacy-84/releases/download/latest/Galaxy-330-2U-GX383-3-1.zip)...

|Description|URL|Example|
|---|---|---|
|Front Panel|[front.fpd](./front.fpd)|[front-3-1.png](../Renders/front-3-1.png)|
|Rear Panel|[rear-rca.fpd](./rear-rca.fpd)|[rear-rca-3-1.png](../Renders/rear-3-1-rca.png)|
|Top Panel|[top.fpd](./top.fpd)|[gx383-top.png](../Renders/gx383-top.png)|
|Bottom Panel*|[bottom.fpd](./bottom.fpd)|[gx383-bottom.png](../Renders/gx383-bottom.png)|

\* Alternatively you can make use of Modushop's Fully vented aluminium cover instead of using a customized panel for the bottom. This will safe you the costs for customization, however you will have to drill your own holes for the feet and for the grounding post. You can find the Fully vented aluminium cover [here](https://modushop.biz/site/index.php?route=product/product&product_id=589).

## GX383 Chassis
|Description|URL|Color|
|---|---|---|
|GX383 Chassis|https://modushop.biz/site/index.php?route=product/product&product_id=445|Silver|
|GX383 Chassis|https://modushop.biz/site/index.php?route=product/product&product_id=446|Black|

## Customization Options
|Description|URL|Option|Amount|
|---|---|---|---|
|Drilling panel 2/3/4mm|https://modushop.biz/site/index.php?route=product/product&product_id=490|More than 40 holes|3x|
|Drilling front panel 10mm|https://modushop.biz/site/index.php?route=product/product&product_id=489|Customized on front/rear part of the panel|1x|
|Digital Printing|https://modushop.biz/site/index.php?route=product/product&product_id=579||2x|

## Optional Parts
Order these optional parts to complete your Amplifier.
|Description|URL|Amount|
|---|---|---|
|Anti-Vibration Feet|https://modushop.biz/site/index.php?route=product/category&path=313|1x|
|Aluminium knob 24.5 mm|https://modushop.biz/site/index.php?route=product/product&path=312&product_id=755|1x|
|Aluminium knob 39.5 mm|https://modushop.biz/site/index.php?route=product/product&path=312&product_id=757|1x|

## How to order
1. Create an account with [Modushop](https://modushop.biz/) if you are not yet already registered.
2. Select the chassis that you want and add it to your shopping cart.
3. Find the customization options and add them to your shopping cart.
4. Add the optional parts to your shopping cart.
5. Checkout your shopping cart. You will receive an order ID and payment instructions.
6. Send an email with the FPD files attached to info@modushop.biz. Mention your order ID in the email so Modushop can link it to your order.
7. Modushop will process your order for a custom chassis once the payment has been processed. 

# Transformers
The drawings that are provided here make use of customized transformers from [Automatic Electric Europe](https://www.aeetransformers.com/) (AEE). Both the Legacy 84 and the Impact 84 use the exact same transformers.

You can order the transformers by sending an [email](info@ae-europe.nl) to AEE. Send them the name of the product that you are building (Legacy 84 or Impact 84) so they have context and use the lookup table below for the correct part numbers
|Description|Part number|Amount|
|---|---|---|
|Power Transformer 230V primary*|15236-POT|1x|
|Power Transformer 110V primary*|15236-POT-US|1x|
|Output transformer EL84 Pushpull 10k primary|15237-POT|2x|

\* Only order the Power Transformer that is suitable for your mains voltage.

### Example email
```
To: info@ae-europe.nl  
Subject: Transformers for Legacy 84 Stereo amplifier kit  
Message:  
Dear AEE,  

I have ordered the STE-Labs Legacy 84 Stereo amplifier kit together with a customized enclosure from Modushop. I would like to order the complementary transformers with you. My build requires these transformers:  
- 1x 15236-POT  
- 2x 15237-POT  

Best regards,  
Builder
```

# PCB Kits
We supply all the internal PCBs that you need to build a full amplifier. If you want a perfect build experience then we advice you to order these PCB-kits with us:
|Name|Description|URL|
|---|---|---|
|Legacy 84 Stereo Inverted|Legacy 84 Amplifier PCB with inverted tube sockets||
|Impact 84 Stereo Inverted|Impact 84 Direct Coupled Amplifier PCB with inverted tube sockets||
|IO Board 3:1|IO Board with three inputs and one output with DSP support||
|Power Supply 1|Standby Power Supply with remote switch board||
|GX383-DSP|Complementary kit to complete your build||

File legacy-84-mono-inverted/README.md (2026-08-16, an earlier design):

# Legacy 84 Mono Inverted

## Table of Contents
[Home](../README.md)
- [PCB](#PCB)
  - [PCB Front Side](#PCB-Front-Side)
  - [PCB Back Side](#PCB-Back-Side)
- [Circuit Diagram](#circuit-diagram)
  - [Power Supply](#power-supply)
  - [Negative Power Supply](#negative-power-supply)
  - [Amplifier](#amplifier)
  - [Pure Switch](#pure-switch)
- [Chassis Examples](#chassis-examples)
  - [Modushop Slim Line 2U 230mm](#modushop-slim-line-3u-230mm)
    - [Front Panel](#modushop-slim-line-2u-front-panel)
    - [Back Panel](#modushop-slim-line-2u-back-panel)
    - [Top Panel](#modushop-slim-line-2u-top-panel)
    - [Bottom Panel](#modushop-slim-line-2u-bottom-panel)
  - [Modushop Slim Line 2U 280mm](#modushop-slim-line-2u-280mm)
    - [Front Panel](#modushop-slim-line-2u-front-panel)
    - [Back Panel](#modushop-slim-line-2u-back-panel)
    - [Top Panel](#modushop-slim-line-2u-top-panel)
    - [Bottom Panel](#modushop-slim-line-2u-bottom-panel)
- [Bill of Materials](#bill-of-materials)

## PCB
### PCB Front Side
PCB Front

### PCB Back Side
PCB Back

## Circuit Diagram
### Power Supply
Circuit Diagram Power Supply</br>
[High Resolution](./docs/circuit-diagram-power-supply.png)</br>
[PDF](./docs/circuit-diagram-power-supply.pdf)</br>

### Negative Power Supply
Circuit Diagram Negative Power Supply</br>
[High Resolution](./docs/circuit-diagram-negative-power-supply.png)</br>
[PDF](./docs/circuit-diagram-negative-power-supply.pdf)</br>

### Amplifier
Circuit Diagram Amplifier</br>
[High Resolution](./docs/circuit-diagram-amplifier.png)</br>
[PDF](./docs/circuit-diagram-amplifier.pdf)</br>

### Pure Switch
Circuit Diagram Pure Switch</br>
[High Resolution](./docs/circuit-diagram-pure-switch.png)</br>
[PDF](./docs/circuit-diagram-pure-switch.pdf)</br>

## Chassis Examples
### Modushop Galaxy 2U 230mm

### Modushop Galaxy 2U 280mm

### Modushop Slim Line 2U 230mm
Slim Line 2U/230 Silver</br>
[Slim Line 2U/230 Silver](https://modushop.biz/site/index.php?route=product/product&path=120_246_249&product_id=97)</br></br>
Slim Line 2U/230 Black</br>
[Slim Line 2U/230 Black](https://modushop.biz/site/index.php?route=product/product&path=120_246_249&product_id=98)</br>

|Panel|File|
|---|---|
|Front|[Slim Line 2U Front](../Chassis/Slimline/2U/Front.fpd)|
|Rear RCA|[Slim Line 2U Rear RCA](../Chassis/Slimline/2U/Rear-RCA.fpd)|
|Rear XLR|[Slim Line 2U Rear XLR](../Chassis/Slimline/2U/Rear-XLR.fpd)|
|Top|[Slim Line 2U Top 230](../Chassis/Slimline/2U/230/Top.fpd)|
|Bottom|[Slim Line 2U Bottom 230](../Chassis/Slimline/2U/230/Bottom.fpd)|

#### Front Panel
Modushop Slim Line 2U Front Panel</br>
#### Back Panel RCA
Modushop Slim Line 2U Back Panel RCA</br>
#### Back Panel XLR
Modushop Slim Line 2U Back Panel XLR</br>
#### Top Panel
Modushop Slim Line 2U Top Panel 230mm</br>
#### Bottom Panel
Modushop Slim Line 2U Bottom Panel 230mm</br>

### Modushop Slim Line 2U 280mm
Slim Line 2U/280 Silver</br>
[Slim Line 2U/280 Silver](https://modushop.biz/site/index.php?route=product/product&path=120_246_249&product_id=99)</br></br>
Slim Line 2U/280 Black</br>
[Slim Line 2U/280 Black](https://modushop.biz/site/index.php?route=product/product&path=120_246_249&product_id=100)</br>

|Panel|File|
|---|---|
|Front|[Slim Line 2U Front](../Chassis/Slimline/2U/Front.fpd)|
|Rear RCA|[Slim Line 2U Rear RCA](../Chassis/Slimline/2U/Rear-RCA.fpd)|
|Rear XLR|[Slim Line 2U Rear XLR](../Chassis/Slimline/2U/Rear-XLR.fpd)|
|Top|[Slim Line 2U Top 280](../Chassis/Slimline/2U/280/Top.fpd)|
|Bottom|[Slim Line 2U Bottom 280](../Chassis/Slimline/2U/280/Bottom.fpd)|

#### Front Panel
Modushop Slim Line 2U Front Panel</br>
#### Back Panel RCA
Modushop Slim Line 2U Back Panel RCA</br>
#### Back Panel XLR
Modushop Slim Line 2U Back Panel XLR</br>
#### Top Panel
Modushop Slim Line 2U Top Panel 280mm</br>
#### Bottom Panel
Modushop Slim Line 2U Bottom Panel 280mm</br>

## Bill of Materials

- [ ] 2x 100 Resistor
- [ ] 3x 100/2W Resistor
- [ ] 1x 100/35W Resistor
- [ ] 7x 100k Resistor
- [ ] 1x 100k Resistor (2W)
- [ ] 2x 100k Trimm Resistor
- [ ] 1x 100k/2W Resistor
- [ ] 1x 100n Capacitor
- [ ] 2x 100n/400V Capacitor
- [ ] 1x 100nF Capacitor
- [ ] 1x 100u/100V Polarized Capacitor
- [ ] 2x 100uF/25V Polarized Capacitor
- [ ] 2x 10_270/2W Cathode Resistor
- [ ] 3x 10k Resistor
- [ ] 2x 110 Resistor
- [ ] 2x 1M Resistor
- [ ] 1x 1N4148 Diode
- [ ] 7x 1k Resistor
- [ ] 2x 1u/400V Coupling Capacitor
- [ ] 2x 1u/50V Polarized Capacitor
- [ ] 2x 2.2k/2W Resistor
- [ ] 2x 2.7k Resistor
- [ ] 1x 2.7k/2W Resistor
- [ ] 1x 22 Resistor
- [ ] 1x 220u/16V Polarized Capacitor
- [ ] 2x 220u/450V Polarized Capacitor
- [ ] 2x 22p Capacitor
- [ ] 1x 270k/2W Resistor
- [ ] 2x 27k Resistor
- [ ] 1x 30 Resistor
- [ ] 2x 4.7k Resistor
- [ ] 5x 470 Resistor
- [ ] 2x 470k/2W Resistor
- [ ] 2x 470u/100V Polarized Capacitor
- [ ] 1x 47k/2W Resistor
- [ ] 1x 47u/450V Polarized Capacitor
- [ ] 1x B3B-ZR Connector
- [ ] 1x BC547 NPN Transistor
- [ ] 1x BS170 N-Channel MOS FET
- [ ] 1x BZX55C15 Z Diode
- [ ] 1x BZX55C2V7 Z Diode
- [ ] 2x BZX55C5V1 Z Diode
- [ ] 8x C3D03060A Diode
- [ ] 2x ECC88 Valve
- [ ] 2x EL84 Valve
- [ ] 1x G6K-2P-Y Relay
- [ ] 2x IRF820 N-Channel MOS FET
- [ ] 3x MKDSN1,5/2-5,08 Terminal Block
- [ ] 2x MKDSN1,5/3-5,08 Terminal Block
- [ ] 1x MPSA42 Transistor
- [ ] 1x PC817 Opto Coupler
- [ ] 3x SK104-PAD Heatsink
- [ ] 8x SK95-2M3 Heatsink
- [ ] 2x ST-SMB-V SMB Connector
- [ ] 2x T 315mA Fuse Holder
- [ ] 1x T3A Fuse Holder
- [ ] 1x UF4003 Diode

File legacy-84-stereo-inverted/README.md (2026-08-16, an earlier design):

# Legacy 84 Stereo Inverted

## Table of Contents
[Home](../README.md)
- [PCB](#pcb)
  - [PCB Front Side](#pcb-front-side)
  - [PCB Back Side](#pcb-back-side)
- [Circuit Diagram Left Channel](#circuit-diagram-left-channel)
  - [Power Supply](#power-supply)
  - [Negative Power Supply](#negative-power-supply)
  - [Amplifier](#amplifier)
- [Circuit Diagram Right Channel](#circuit-diagram-right-channel)
  - [Power Supply](#power-supply-1)
  - [Negative Power Supply](#negative-power-supply-1)
  - [Amplifier](#amplifier-1)
- [Circuit Diagram Pure Switch](#circuit-diagram-pure-switch)
- [Chassis Examples](#chassis-examples)
  - [Modushop Galaxy 2U GX383 & GX388](#modushop-galaxy-2u-gx383--gx388)
- [Bill of Materials](#bill-of-materials)

## PCB
### PCB Front Side
PCB Front

### PCB Back Side
PCB Back

## Circuit Diagram Left Channel
### Power Supply
Circuit Diagram Left Channel Power Supply</br>
[High Resolution](./docs/circuit-diagram-left-channel-power-supply.png)</br>
[PDF](./docs/circuit-diagram-left-channel-power-supply.pdf)</br>

### Negative Power Supply
Circuit Diagram Left Channel Negative Power Supply</br>
[High Resolution](./docs/circuit-diagram-left-channel-negative-power-supply.png)</br>
[PDF](./docs/circuit-diagram-left-channel-negative-power-supply.pdf)</br>

### Amplifier
Circuit Diagram Left Channel Amplifier</br>
[High Resolution](./docs/circuit-diagram-left-channel-amplifier.png)</br>
[PDF](./docs/circuit-diagram-left-channel-amplifier.pdf)</br>

## Circuit Diagram Right Channel
### Power Supply
Circuit Diagram Right Channel Power Supply</br>
[High Resolution](./docs/circuit-diagram-right-channel-power-supply.png)</br>
[PDF](./docs/circuit-diagram-right-channel-power-supply.pdf)</br>

### Negative Power Supply
Circuit Diagram Right Channel Negative Power Supply</br>
[High Resolution](./docs/circuit-diagram-right-channel-negative-power-supply.png)</br>
[PDF](./docs/circuit-diagram-right-channel-negative-power-supply.pdf)</br>

### Amplifier
Circuit Diagram Right Channel Amplifier</br>
[High Resolution](./docs/circuit-diagram-right-channel-amplifier.png)</br>
[PDF](./docs/circuit-diagram-right-channel-amplifier.pdf)</br>

## Circuit Diagram Pure Switch
Circuit Diagram Pure Switch</br>
[High Resolution](./docs/circuit-diagram-pure-switch.png)</br>
[PDF](./docs/circuit-diagram-pure-switch.pdf)</br>

## Chassis Examples
### Modushop Galaxy 2U GX383 & GX388
Panel drawings for the Legacy 84 Stereo Inverted in a Galaxy 2U enclosure.

[View Chassis Details](../Chassis/Galaxy/330/2U/README.md)

## Bill of Materials

- [ ] 4x 100 Resistor
- [ ] 6x 100/2W Resistor
- [ ] 2x 100/35W Resistor
- [ ] 14x 100k Resistor
- [ ] 2x 100k Resistor (2W)
- [ ] 4x 100k Trimm Resistor
- [ ] 2x 100k/2W Resistor
- [ ] 2x 100n Capacitor
- [ ] 4x 100n/400V Capacitor
- [ ] 1x 100nF Capacitor
- [ ] 2x 100u/100V Polarized Capacitor
- [ ] 4x 100u/25V Polarized Capacitor
- [ ] 4x 10_270/2W Cathode Resistor
- [ ] 5x 10k Resistor
- [ ] 4x 110 Resistor
- [ ] 4x 1M Resistor
- [ ] 2x 1N4148 Diode
- [ ] 11x 1k Resistor
- [ ] 4x 1u/400V Coupling Capacitor
- [ ] 4x 1u/50V Polarized Capacitor
- [ ] 4x 2.2k/2W Resistor
- [ ] 6x 2.7k Resistor
- [ ] 2x 2.7k/2W Resistor
- [ ] 2x 22 Resistor
- [ ] 2x 220u/16V Polarized Capacitor
- [ ] 4x 220u/450V Polarized Capacitor
- [ ] 4x 22p Capacitor
- [ ] 2x 270k/2W Resistor
- [ ] 4x 27k Resistor
- [ ] 2x 30 Resistor
- [ ] 4x 4.7k Resistor
- [ ] 10x 470 Resistor
- [ ] 4x 470k/2W Resistor
- [ ] 4x 470u/100V Polarized Capacitor
- [ ] 2x 47k/2W Resistor
- [ ] 2x 47u/450V Polarized Capacitor
- [ ] 1x B3B-ZR Connector
- [ ] 2x BC547 NPN Transistor
- [ ] 1x BS170 N-Channel MOS FET
- [ ] 2x BZX55C15 Z Diode
- [ ] 2x BZX55C2V7 Z Diode
- [ ] 2x BZX55C5V1 Z Diode (DO41Z10)
- [ ] 1x BZX55C5V1 Z Diode (DO35-7)
- [ ] 16x C3D03060A Diode
- [ ] 4x ECC88 Valve
- [ ] 4x EL84 Valve
- [ ] 2x G6K-2P-Y Relay
- [ ] 4x IRF820 N-Channel MOS FET
- [ ] 6x MKDSN1,5/2-5,08 Terminal Block
- [ ] 4x MKDSN1,5/3-5,08 Terminal Block
- [ ] 2x MPSA42 Transistor
- [ ] 2x PC817 Opto Coupler
- [ ] 6x SK104-PAD Heatsink
- [ ] 16x SK95-2M3 Heatsink
- [ ] 4x ST-SMB-V SMB Connector
- [ ] 4x T250mA Fuse Holder
- [ ] 2x T2A Fuse Holder
- [ ] 2x UF4003 Diode

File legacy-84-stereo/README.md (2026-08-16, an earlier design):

# Legacy 84 Stereo

## Table of Contents
[Home](../README.md)
- [PCB](#PCB)
  - [PCB Front Side](#PCB-Front-Side)
  - [PCB Back Side](#PCB-Back-Side)
- [Circuit Diagram Left Channel](#circuit-diagram-left-channel)
  - [Power Supply](#power-supply)
  - [Negative Power Supply](#negative-power-supply)
  - [Amplifier](#amplifier)
- [Circuit Diagram Right Channel](#circuit-diagram-right-channel)
  - [Power Supply](#power-supply-1)
  - [Negative Power Supply](#negative-power-supply-1)
  - [Amplifier](#amplifier-1)
- [Circuit Diagram Pure Switch](#circuit-diagram-pure-switch)
- [Chassis Examples](#chassis-examples)
  - [Modushop Slim Line 3U 280mm](#modushop-slim-line-3u-280mm)
    - [Front Panel](#modushop-slim-line-3u-front-panel)
    - [Back Panel](#modushop-slim-line-3u-back-panel)
    - [Top Panel](#modushop-slim-line-3u-top-panel)
    - [Bottom Panel](#modushop-slim-line-3u-bottom-panel)
  - [Modushop Slim Line 3U 350mm](#modushop-slim-line-3u-350mm)
    - [Front Panel](#modushop-slim-line-3u-front-panel)
    - [Back Panel](#modushop-slim-line-3u-back-panel)
    - [Top Panel](#modushop-slim-line-3u-top-panel)
    - [Bottom Panel](#modushop-slim-line-3u-bottom-panel)
  - [Modushop Slim Line 4U 280mm](#modushop-slim-line-4u-280mm)
    - [Front Panel](#modushop-slim-line-4u-front-panel)
    - [Back Panel](#modushop-slim-line-4u-back-panel)
    - [Top Panel](#modushop-slim-line-4u-top-panel)
    - [Bottom Panel](#modushop-slim-line-4u-bottom-panel)
  - [Modushop Slim Line 4U 350mm](#modushop-slim-line-4u-350mm)
    - [Front Panel](#modushop-slim-line-4u-front-panel)
    - [Back Panel](#modushop-slim-line-4u-back-panel)
    - [Top Panel](#modushop-slim-line-4u-top-panel)
    - [Bottom Panel](#modushop-slim-line-4u-bottom-panel)
- [Bill of Materials](#bill-of-materials)

## PCB
### PCB Front Side
PCB Front

### PCB Back Side
PCB Back

## Circuit Diagram Left Channel
### Power Supply
Circuit Diagram Left Channel Power Supply</br>
[High Resolution](./docs/circuit-diagram-left-channel-power-supply.png)</br>
[PDF](./docs/circuit-diagram-left-channel-power-supply.pdf)</br>

### Negative Power Supply
Circuit Diagram Left Channel Negative Power Supply</br>
[High Resolution](./docs/circuit-diagram-left-channel-negative-power-supply.png)</br>
[PDF](./docs/circuit-diagram-left-channel-negative-power-supply.pdf)</br>

### Amplifier
Circuit Diagram Left Channel Amplifier</br>
[High Resolution](./docs/circuit-diagram-left-channel.png)</br>
[PDF](./docs/circuit-diagram-left-channel.pdf)</br>

## Circuit Diagram Right Channel
### Power Supply
Circuit Diagram Right Channel Power Supply</br>
[High Resolution](./docs/circuit-diagram-right-channel-power-supply.png)</br>
[PDF](./docs/circuit-diagram-right-channel-power-supply.pdf)</br>

### Negative Power Supply
Circuit Diagram Right Channel Negative Power Supply</br>
[High Resolution](./docs/circuit-diagram-right-channel-negative-power-supply.png)</br>
[PDF](./docs/circuit-diagram-right-channel-negative-power-supply.pdf)</br>

### Amplifier
Circuit Diagram Right Channel Amplifier</br>
[High Resolution](./docs/circuit-diagram-right-channel.png)</br>
[PDF](./docs/circuit-diagram-right-channel.pdf)</br>

## Circuit Diagram Pure Switch
Circuit Diagram Pure Switch</br>
[High Resolution](./docs/circuit-diagram-pure-switch.png)</br>
[PDF](./docs/circuit-diagram-pure-switch.pdf)</br>

## Chassis Examples
### Modushop Slim Line 3U 280mm
Slim Line 3U/280 Silver</br>
[Slim Line 3U/280 Silver](https://modushop.biz/site/index.php?route=product/product&path=118_251_253&product_id=125)</br></br>
Slim Line 3U/280 Black</br>
[Slim Line 3U/280 Black](https://modushop.biz/site/index.php?route=product/product&path=118_251_253&product_id=126)</br>

|Panel|File|
|---|---|
|Front|[Slim Line 3U Front](../Chassis/Slimline/3U/Front.fpd)|
|Rear RCA|[Slim Line 3U Rear RCA](../Chassis/Slimline/3U/Rear-RCA.fpd)|
|Rear XLR|[Slim Line 3U Rear XLR](../Chassis/Slimline/3U/Rear-XLR.fpd)|
|Top|[Slim Line 3U Top 280](../Chassis/Slimline/3U/280/Top.fpd)|
|Bottom|[Slim Line 3U Bottom 280](../Chassis/Slimline/3U/280/Bottom.fpd)|

#### Front Panel
Modushop Slim Line 3U Front Panel</br>
#### Back Panel RCA
Modushop Slim Line 3U Back Panel RCA</br>
#### Back Panel XLR
Modushop Slim Line 3U Back Panel XLR</br>
#### Top Panel
Modushop Slim Line 3U Top Panel 280mm</br>
#### Bottom Panel
Modushop Slim Line 3U Bottom Panel 280mm</br>

### Modushop Slim Line 3U 350mm
Slim Line 3U/350 Silver</br>
[Slim Line 3U/350 Silver](https://modushop.biz/site/index.php?route=product/product&path=118_251_253&product_id=127)</br></br>
Slim Line 3U/350 Black</br>
[Slim Line 3U/350 Black](https://modushop.biz/site/index.php?route=product/product&path=118_251_253&product_id=128)</br>

|Panel|File|
|---|---|
|Front|[Slim Line 3U Front](../Chassis/Slimline/3U/Front.fpd)|
|Rear RCA|[Slim Line 3U Rear RCA](../Chassis/Slimline/3U/Rear-RCA.fpd)|
|Rear XLR|[Slim Line 3U Rear XLR](../Chassis/Slimline/3U/Rear-XLR.fpd)|
|Top|[Slim Line 3U Top 350](../Chassis/Slimline/3U/350/Top.fpd)|
|Bottom|[Slim Line 3U Bottom 350](../Chassis/Slimline/3U/350/Bottom.fpd)|

#### Front Panel
Modushop Slim Line 3U Front Panel</br>
#### Back Panel RCA
Modushop Slim Line 3U Back Panel RCA</br>
#### Back Panel XLR
Modushop Slim Line 3U Back Panel XLR</br>
#### Top Panel
Modushop Slim Line 3U Top Panel 350mm</br>
#### Bottom Panel
Modushop Slim Line 3U Bottom Panel 350mm</br>

### Modushop Slim Line 4U 280mm
Slim Line 4U/280 Silver</br>
[Slim Line 4U/280 Silver](https://modushop.biz/site/index.php?route=product/product&path=121_255_257&product_id=149)</br></br>
Slim Line 4U/280 Black</br>
[Slim Line 4U/280 Black](https://modushop.biz/site/index.php?route=product/product&path=121_255_257&product_id=150)</br>

|Panel|File|
|---|---|
|Front|[Slim Line 4U Front](../Chassis/Slimline/4U/Front.fpd)|
|Rear RCA|[Slim Line 4U Rear RCA](../Chassis/Slimline/4U/Rear-RCA.fpd)|
|Rear XLR|[Slim Line 4U Rear XLR](../Chassis/Slimline/4U/Rear-XLR.fpd)|
|Top|[Slim Line 4U Top 280](../Chassis/Slimline/4U/280/Top.fpd)|
|Bottom|[Slim Line 4U Bottom 280](../Chassis/Slimline/4U/280/Bottom.fpd)|

#### Front Panel
Modushop Slim Line 4U Front Panel</br>
#### Back Panel RCA
Modushop Slim Line 4U Back Panel RCA</br>
#### Back Panel XLR
Modushop Slim Line 4U Back Panel XLR</br>
#### Top Panel
Modushop Slim Line 4U Top Panel 280mm</br>
#### Bottom Panel
Modushop Slim Line 4U Bottom Panel 280mm</br>

### Modushop Slim Line 4U 350mm
Slim Line 4U/350 Silver</br>
[Slim Line 4U/350 Silver](https://modushop.biz/site/index.php?route=product/product&path=121_255_257&product_id=151)</br></br>
Slim Line 4U/350 Black</br>
[Slim Line 4U/350 Black](https://modushop.biz/site/index.php?route=product/product&path=121_255_257&product_id=152)</br>

|Panel|File|
|---|---|
|Front|[Slim Line 4U Front](../Chassis/Slimline/4U/Front.fpd)|
|Rear RCA|[Slim Line 4U Rear RCA](../Chassis/Slimline/4U/Rear-RCA.fpd)|
|Rear XLR|[Slim Line 4U Rear XLR](../Chassis/Slimline/4U/Rear-XLR.fpd)|
|Top|[Slim Line 4U Top 350](../Chassis/Slimline/4U/350/Top.fpd)|
|Bottom|[Slim Line 4U Bottom 350](../Chassis/Slimline/4U/350/Bottom.fpd)|

#### Front Panel
Modushop Slim Line 4U Front Panel</br>
#### Back Panel RCA
Modushop Slim Line 4U Back Panel RCA</br>
#### Back Panel XLR
Modushop Slim Line 4U Back Panel XLR</br>
#### Top Panel
Modushop Slim Line 4U Top Panel 350mm</br>
#### Bottom Panel
Modushop Slim Line 4U Bottom Panel 350mm</br>

## Bill of Materials

- [ ] 4x 100 Resistor
- [ ] 6x 100/2W Resistor
- [ ] 2x 100/35W Resistor
- [ ] 14x 100k Resistor
- [ ] 2x 100k Resistor (2W)
- [ ] 4x 100k Trimm Resistor
- [ ] 2x 100k/2W Resistor
- [ ] 2x 100n Capacitor
- [ ] 4x 100n/400V Capacitor
- [ ] 1x 100nF Capacitor
- [ ] 2x 100u/100V Polarized Capacitor
- [ ] 2x 100u/25 Polarized Capacitor
- [ ] 2x 100u/25V Polarized Capacitor
- [ ] 4x 10_270/2W Cathode Resistor
- [ ] 5x 10k Resistor
- [ ] 4x 110 Resistor
- [ ] 4x 1M Resistor
- [ ] 2x 1N4148 Diode
- [ ] 13x 1k Resistor
- [ ] 4x 1u/400V Coupling Capacitor
- [ ] 4x 1u/50V Polarized Capacitor
- [ ] 4x 2.2k/2W Resistor
- [ ] 4x 2.7k Resistor
- [ ] 2x 2.7k/2W Resistor
- [ ] 2x 22 Resistor
- [ ] 2x 220u/16V Polarized Capacitor
- [ ] 4x 220u/450V Polarized Capacitor
- [ ] 4x 22p Capacitor
- [ ] 2x 270k/2W Resistor
- [ ] 4x 27k Resistor
- [ ] 2x 30 Resistor
- [ ] 4x 4.7k Resistor
- [ ] 10x 470 Resistor
- [ ] 4x 470k/2W Resistor
- [ ] 4x 470u/100V Polarized Capacitor
- [ ] 2x 47k/2W Resistor
- [ ] 2x 47u/450V Polarized Capacitor
- [ ] 1x B3B-ZR Connector
- [ ] 2x BC547 NPN Transistor
- [ ] 1x BS170 N-Channel MOS FET
- [ ] 2x BZX55C15 Z Diode
- [ ] 2x BZX55C2V7 Z Diode
- [ ] 2x BZX55C5V1 Z Diode (DO41Z10)
- [ ] 1x BZX55C5V1 Z Diode (DO35-7)
- [ ] 16x C3D03060A Diode
- [ ] 4x ECC88 Valve
- [ ] 4x EL84 Valve
- [ ] 2x G6K-2P-Y Relay
- [ ] 4x IRF820 N-Channel MOS FET
- [ ] 6x MKDSN1,5/2-5,08 Terminal Block
- [ ] 4x MKDSN1,5/3-5,08 Terminal Block
- [ ] 2x MPSA42 Transistor
- [ ] 2x PC817 Opto Coupler
- [ ] 6x SK104-PAD Heatsink
- [ ] 16x SK95-2M3 Heatsink
- [ ] 4x ST-SMB-V SMB Connector
- [ ] 4x T 315mA Fuse Holder
- [ ] 2x T 3A Fuse Holder
- [ ] 2x UF4003 Diode

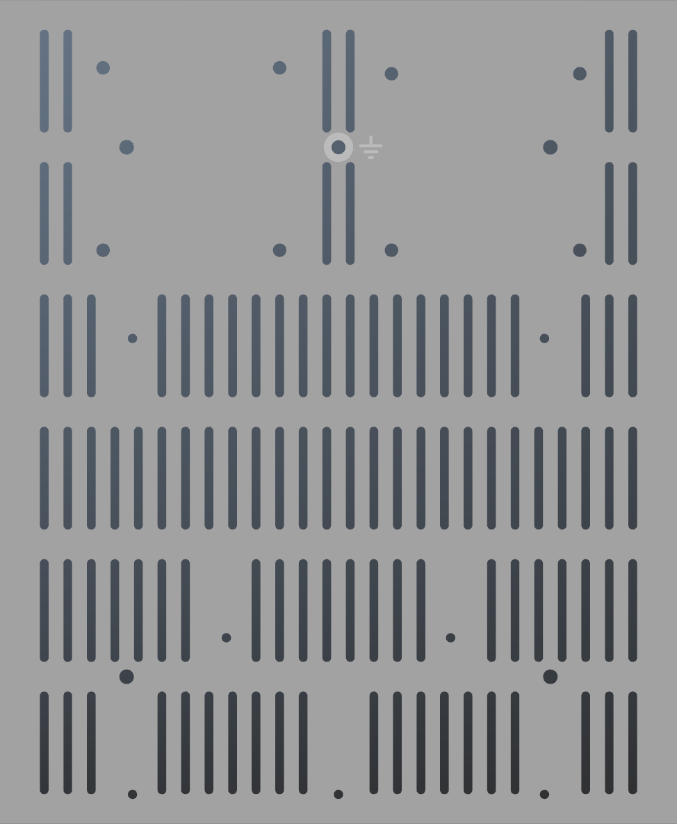
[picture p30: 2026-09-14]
Chassis/Galaxy/230/4U/docs/bottom-gx288.png

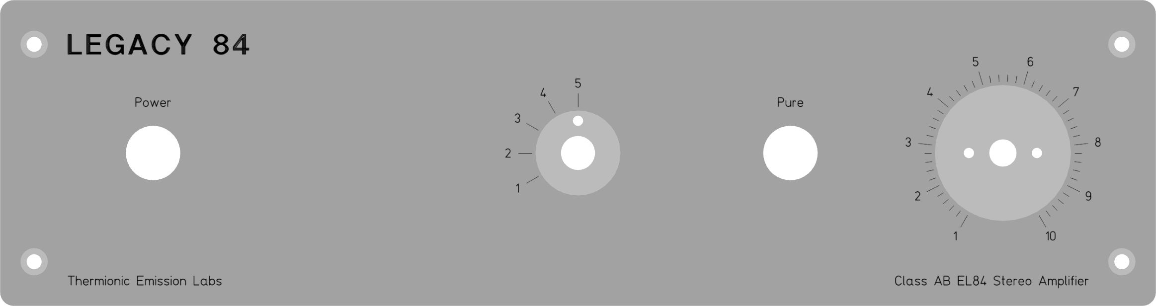
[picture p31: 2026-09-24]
Chassis/Galaxy/330/2U/Renders/front-5-0.png

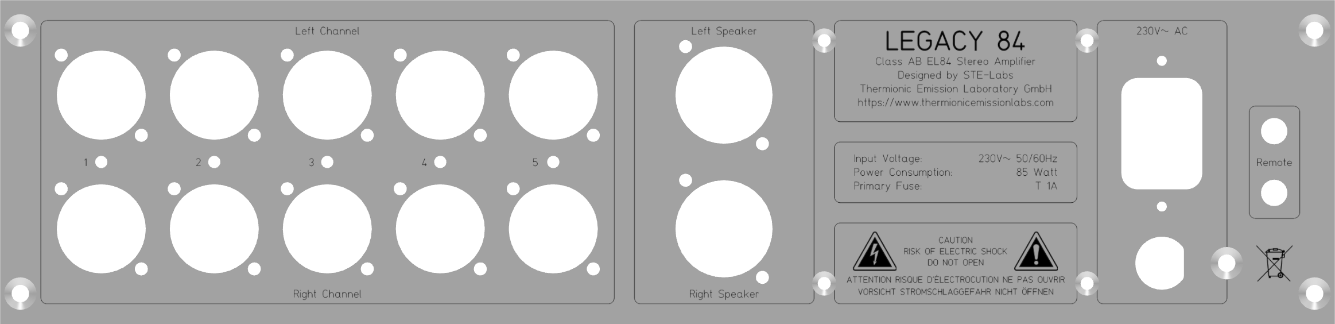
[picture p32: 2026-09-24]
Chassis/Galaxy/330/2U/Renders/rear-5-0-xlr.png

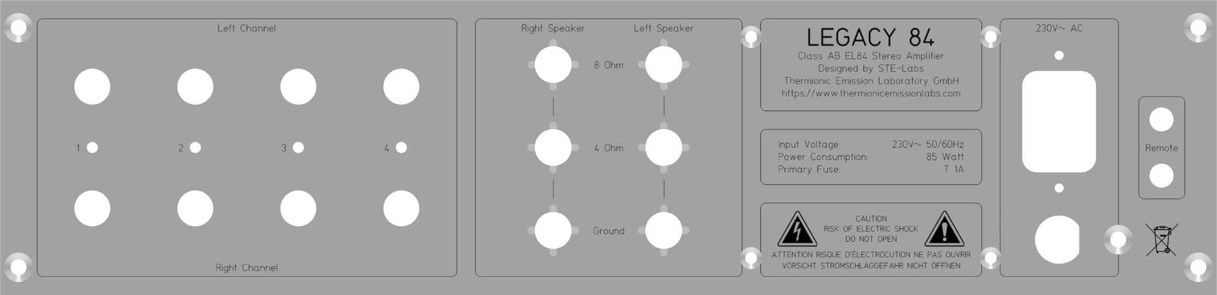
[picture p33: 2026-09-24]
Chassis/Galaxy/330/2U/Renders/rear-4-0-rca.png

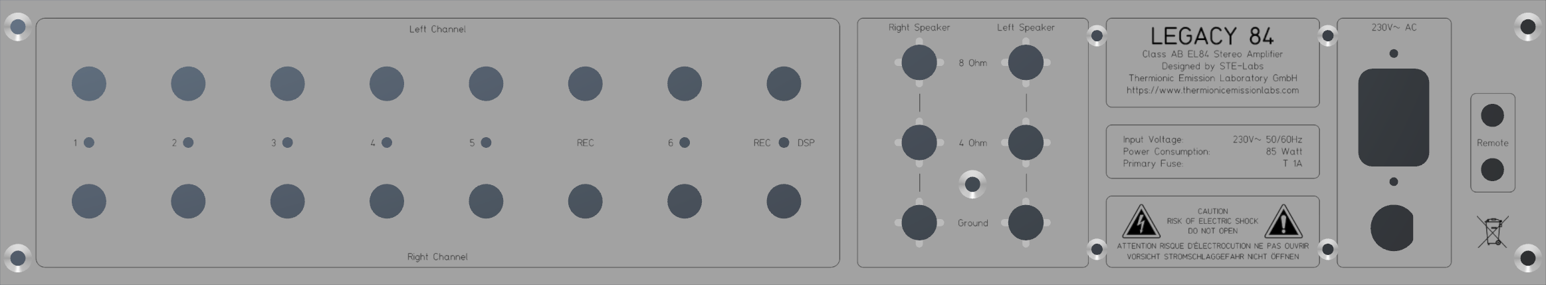
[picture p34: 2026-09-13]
Chassis/Slimline/2U/docs/rear-rca.png

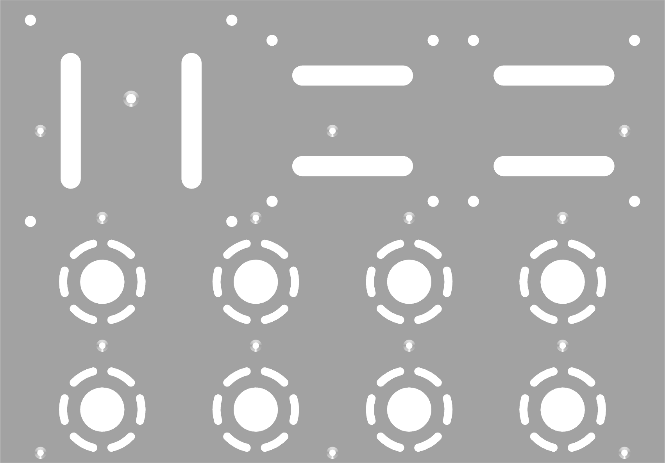
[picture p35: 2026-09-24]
Chassis/Galaxy/330/2U/Renders/gx383-top.png

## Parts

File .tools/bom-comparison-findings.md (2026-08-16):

# Legacy 84 BOM Comparison Findings

Date: 2026-08-16

## Overview

Four BOMs were compared across the Legacy 84 variants:

- **legacy-84-mono** (mono, upright tubes)
- **legacy-84-mono-inverted** (mono, inverted tubes)
- **legacy-84-stereo** (stereo, upright tubes)
- **legacy-84-stereo-inverted** (stereo, inverted tubes)

Mono and Mono-Inverted should have identical component counts (only tube socket packages differ).
Stereo variants should generally have 2x the mono component counts, except for shared components
(pure switch circuit: B3B-ZR, BS170, BZX55C5V1, 100nF capacitor, and one 10k/1k resistor).

---

## Expected Differences (by design)

### Tube Socket Packages

| Component | Mono / Stereo | Mono-Inv / Stereo-Inv |
|---|---|---|
| ECC88 | ECC88-P (NOVAL1) | ECC88-POI (NOVAL1_INVERTED)  |
| EL84 | EL84-PO (NOVAL1) | EL84-POI (NOVAL1_INVERTED) |

This is correct — inverted variants use inverted tube socket footprints.

### Shared Components (not doubled in stereo)

The following are shared across both channels in the stereo variants and correctly appear as 1x:

- B3B-ZR connector (1x)
- BS170 N-Channel MOS FET (1x)
- BZX55C5V1 zener diode, DO35-7 (1x)
- 100nF capacitor (1x)

The 10k and 1k resistors scale as +1 (shared) rather than exactly 2x, which is also expected.

---

## Inconsistencies Found

### 1. Value Naming: 100u/25V Capacitor (Cosmetic)

| BOM | Value Used | Parts |
|---|---|---|
| Mono | 100u/25V | C310, C311 |
| Mono-Inverted | 100uF/25V | C310, C311 |
| Stereo (line 1)  | 100u/25V | C310, C311 |
| Stereo (line 2)  | 100u/25 | C610, C611 |
| Stereo-Inverted  | 100u/25V | C310-C611 |

**Problem:** Three different value strings for the same component. The Stereo BOM splits the
same part across two lines with different names ("100u/25V" and "100u/25"), and the Mono-Inverted
BOM uses "100uF/25V" instead of "100u/25V".

**Recommendation:** Standardize all to "100u/25V".

---

### 2. Fuse Value Naming: "T 3A" vs "T3A" (Cosmetic)

| BOM | Value  | Part |
|---|---|---|
| Mono | T 3A | F102 |
| Mono-Inverted | T3A | F102 |

**Problem:** Inconsistent spacing in the fuse value name.

**Recommendation:** Use consistent formatting, e.g., "T 3A" with a space.

---

### 3. Fuse Ratings Differ Between Normal and Inverted Variants

| BOM | HV Fuse | LV Fuse |
|---|---|---|
| Mono | T 3A (F102) | T 315mA (F101, F201) |
| Mono-Inverted | T3A (F102) | T 315mA (F101, F201) |
| Stereo | T 3A (F102, F402) | T 315mA (F101, F201, F401, F501) |
| Stereo-Inverted  | T2A (F101, F402) | T250mA (F102, F201, F401, F501)  |

**Problems:**
1. Fuse ratings are different: Normal variants use 3A + 315mA, Inverted variants use 2A + 250mA.
   Is this intentional due to the inverted circuit design, or an error?
2. In Stereo-Inverted, the part designators are swapped: F101 is the HV fuse and F102 is the LV
   fuse, which is the opposite of the Stereo variant.

**Recommendation:** Verify whether the different fuse ratings are intentional. If not, align them.
Also verify the F101/F102 assignment in Stereo-Inverted.

---

### 4. R629 and R630: 1k vs 2.7k (Potential Circuit Error)

| BOM | R629/R630 Value | 1k Total | 2.7k Total |
|---|---|---|---|
| Stereo | 1k | 13 | 4 |
| Stereo-Inverted  | 2.7k | 11 | 6 |

**Problem:** R629 and R630 are listed as 1k resistors in the Stereo BOM but as 2.7k resistors in
the Stereo-Inverted BOM. The total counts shift accordingly (Stereo has 13x 1k and 4x 2.7k,
while Stereo-Inverted has 11x 1k and 6x 2.7k).

**This is the most significant finding** — one of these BOMs has the wrong resistor value for
R629/R630. This could affect the circuit behavior.

**Recommendation:** Check the schematic to determine the correct value for R629 and R630.

---

### 5. Tube Part Designator Assignment in Stereo-Inverted

| BOM | ECC88 (Input Tubes) | EL84 (Output Tubes) |
|---|---|---|
| Stereo | V101, V103, V401, V403 | V102, V104, V402, V404 |
| Stereo-Inverted  | V103, V104, V401, V403 | V101, V102, V402, V404 |

**Problem:** In the Stereo-Inverted BOM, V104 is listed as an ECC88 (input tube) and V101 is
listed as an EL84 (output tube). In every other BOM, even-numbered tubes (V102, V104) are always
EL84 and odd-numbered tubes (V101, V103) are always ECC88.

**Recommendation:** Verify whether this swap is intentional for the inverted layout or if V101
should be ECC88 and V104 should be EL84.

---

## Summary Table

| #  | Issue | Severity | Action Needed |
|----|---|---|---|
| 1  | 100u/25V vs 100uF/25V vs 100u/25 naming | Low | Standardize naming |
| 2  | "T 3A" vs "T3A" spacing | Low | Standardize naming |
| 3  | Fuse ratings: 3A/315mA vs 2A/250mA | Medium | Verify if intentional |
| 4  | R629/R630: 1k (Stereo) vs 2.7k (Stereo-Inv) | High | Check schematic |
| 5  | V101/V104 tube type swap in Stereo-Inverted | Medium | Verify if intentional |

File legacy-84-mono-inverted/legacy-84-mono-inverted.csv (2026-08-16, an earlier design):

Qty | Value | Device | Package | Parts | Description | MF | MPN | OC_FARNELL | OC_NEWARK | POPULARITY | SPICEMODEL | SPICEPREFIX | SPICEPREFIXL
8 |  | 2,15/1,0 | 2,15/1,0 | PAD101, PAD103, PAD104, PAD201, PAD301, PAD302, PAD303, PAD304 | THROUGH-HOLE PAD |  |  |  |  | 11
1 |  | 3,81/1,4 | 3,81/1,4 | PAD102 | THROUGH-HOLE PAD |  |  |  |  | 14
2 | 100 | R-EU_0207/10 | 0207/10 | R111, R305 | RESISTOR, European symbol |  |  |  |  | 81 |  | R
3 | 100/2W | R-EU_0411/15 | 0411/15 | R106, R107, R202 | RESISTOR, European symbol |  |  |  |  | 1 |  | R
1 | 100/35W | PWR220T | TO220-2 | R102
7 | 100k | R-EU_0207/10 | 0207/10 | R301, R302, R303, R319, R320, R321, R322 | RESISTOR, European symbol |  |  |  |  | 81 |  | R
1 | 100k | R-EU_0411/15 | 0411/15 | R110 | RESISTOR, European symbol |  |  |  |  | 1 |  | R
2 | 100k | R-TRIMM3296W | RTRIM3296W | R324, R327 | Trimm resistor |  |  |  |  | 3 | X |  | POT
1 | 100k/2W | R-EU_0411/15 | 0411/15 | R201 | RESISTOR, European symbol |  |  |  |  | 1 |  | R
1 | 100n | C-EU102-054X133 | C102-054X133 | C301 | CAPACITOR, European symbol |  |  |  |  | 0 |  | C
2 | 100n/400V | C-EU150-072X183 | C150-072X183 | C306, C307 | CAPACITOR, European symbol |  |  |  |  | 0 |  | C
1 | 100nF | C-EU050-025X075 | C050-025X075 | C401 | CAPACITOR, European symbol |  |  |  |  | 29 |  | C
1 | 100u/100V | CPOL-EUE5-10.5 | E5-10,5 | C103 | POLARIZED CAPACITOR, European symbol |  |  |  |  | 23 |  | C
2 | 100uF/25V | CPOL-EUE5-8.5 | E5-8,5 | C310, C311 | POLARIZED CAPACITOR, European symbol |  |  |  |  | 0 |  | C
2 | 10_270/2W | CATHODE_RESISTOR | 0411/15 | R331, R332
3 | 10k | R-EU_0207/10 | 0207/10 | R307, R308, R401 | RESISTOR, European symbol |  |  |  |  | 81 |  | R
2 | 110 | R-EU_0207/10 | 0207/10 | R316, R317 | RESISTOR, European symbol |  |  |  |  | 81 |  | R
2 | 1M | R-EU_0207/10 | 0207/10 | R323, R328 | RESISTOR, European symbol |  |  |  |  | 81 |  | R
1 | 1N4148 | 1N4148DO35-7 | DO35-7 | D401 | DIODE |  |  |  |  | 58
7 | 1k | R-EU_0207/10 | 0207/10 | R112, R115, R313, R314, R329, R330, R402 | RESISTOR, European symbol |  |  |  |  | 81 |  | R
2 | 1u/400V | COUPLING_CAP_HOLES | COUPLING_CAP_HOLES | C304, C305
2 | 1u/50V | CPOL-EUE2.5-5 | E2,5-5 | C308, C309 | POLARIZED CAPACITOR, European symbol |  |  |  |  | 16 |  | C
2 | 2.2k/2W | R-EU_0411/15 | 0411/15 | R108, R109 | RESISTOR, European symbol |  |  |  |  | 1 |  | R
2 | 2.7k | R-EU_0207/10 | 0207/10 | R311, R312 | RESISTOR, European symbol |  |  |  |  | 81 |  | R
1 | 2.7k/2W | R-EU_0411/15 | 0411/15 | R104 | RESISTOR, European symbol |  |  |  |  | 1 |  | R
1 | 22 | R-EU_0207/10 | 0207/10 | R105 | RESISTOR, European symbol |  |  |  |  | 81 |  | R
1 | 220u/16V | CPOL-EUE5-8.5 | E5-8,5 | C105 | POLARIZED CAPACITOR, European symbol |  |  |  |  | 0 |  | C
2 | 220u/450V | CPOL-EUE10-30 | EB30D | C101, C102 | POLARIZED CAPACITOR, European symbol |  |  |  |  | 0 |  | C
2 | 22p | C-EU025-025X050 | C025-025X050 | C302, C303 | CAPACITOR, European symbol |  |  |  |  | 65 |  | C
1 | 270k/2W | R-EU_0411/15 | 0411/15 | R113 | RESISTOR, European symbol |  |  |  |  | 1 |  | R
2 | 27k | R-EU_0207/10 | 0207/10 | R325, R326 | RESISTOR, European symbol |  |  |  |  | 81 |  | R
1 | 30 | R-EU_0207/10 | 0207/10 | R306 | RESISTOR, European symbol |  |  |  |  | 81 |  | R
2 | 4.7k | R-EU_0207/10 | 0207/10 | R309, R310 | RESISTOR, European symbol |  |  |  |  | 81 |  | R
5 | 470 | R-EU_0207/10 | 0207/10 | R304, R315, R318, R333, R334 | RESISTOR, European symbol |  |  |  |  | 81 |  | R
2 | 470k/2W | R-EU_0411/15 | 0411/15 | R101, R103 | RESISTOR, European symbol |  |  |  |  | 1 |  | R
2 | 470u/100V | CPOL-EUE7.5-16 | E7,5-16 | C201, C202 | POLARIZED CAPACITOR, European symbol |  |  |  |  | 4 |  | C
1 | 47k/2W | R-EU_0411/15 | 0411/15 | R114 | RESISTOR, European symbol |  |  |  |  | 1 |  | R
1 | 47u/450V | CPOL-EUE7.5-18 | E7,5-18 | C104 | POLARIZED CAPACITOR, European symbol |  |  |  |  | 6 |  | C
1 | B3B-ZR | B3B-ZR | B3B-ZR | X401 | ZH CONNECTOR 1.5 mm, 4 pin 1 row
1 | BC547 | BC547 | TO92-CBE | Q301 | NPN TRANSISTOR
1 | BS170 | BS170TO-92 | TO92-LINE | Q401 | N-CHANNEL MOS FET
1 | BZX55C15 | 1N4728DO35-7 | DO35-7 | D402 | Z DIODE
1 | BZX55C2V7 | 1N4728 | DO41Z10 | D106 | Z DIODE |  |  |  |  | 6
1 | BZX55C5V1 | 1N4728 | DO41Z10 | D105 | Z DIODE |  |  |  |  | 6
1 | BZX55C5V1 | 1N4728DO35-7 | DO35-7 | D403 | Z DIODE
8 | C3D03060A | BYW80 | TO220ACS | D101, D102, D103, D104, D201, D202, D203, D204 | DIODE |  |  |  |  | 0
2 | ECC88 | ECC88-POI | NOVAL1_INVERTED | V101, V103
2 | EL84 | EL84-POI | NOVAL1_INVERTED | V102, V104
1 | G6K-2P-Y | G6K-2P-Y | G6K-2P-Y | K301 | Low Signal Relay | OMRON COMPONENTS USA | G6K-2P-Y DC12 | 3937276 | 34C3464 | 0
1 | IRF820 | IRF740 | TO220BV | Q302 | N-CHANNEL MOS FET |  |  |  |  | 0
1 | IRF820 | IRF740H | TO220AVH | Q101 | N-CHANNEL MOS FET
3 | MKDSN1,5/2-5,08 | MKDSN1,5/2-5,08 | MKDSN1,5/2-5,08 | X101, X102, X201 | MKDSN 1,5/ 2-5,08 Printklemme |  |  |  |  | 14
2 | MKDSN1,5/3-5,08 | MKDSN1,5/3-5,08 | MKDSN1,5/3-5,08 | X103, X104 | MKDSN 1,5/ 3-5,08 Printklemme |  |  |  |  | 0
1 | MPSA42 | MPSA42 | TO92-EBC | Q102
1 | PC817 | PC817 | DIL04 | OK101 | SHARP OPTO COUPLER |  | PC817X4J000F | 9707727 | 97K7059 | 20
3 | SK104-PAD | SK104-PAD | SK104-PAD | KK509, KK510, KK511 | HEATSINK manufacturer Fischer/distributor Buerklin |  |  |  |  | 4
8 | SK95-2M3 | SK95-2M3 | SK95-2M3 | KK501, KK502, KK503, KK504, KK505, KK506, KK507, KK508 | HEATSINK manufacturer Fischer/distributor Buerklin |  |  |  |  | 0
2 | ST-SMB-V | ST-SMB-V | ST-SMB-V | X301, X302 | MALE SMB CONNECTOR |  |  | unknown | unknown | 0
2 | T 315mA | SH22,5 | SH22,5 | F101, F201 | FUSE HOLDER grid 22,5 mm, OGN0031 8201, Schurter (Buerklin) | SCHURTER | 0031.8201 | 1162740 | 96F8317 | 6
1 | T3A | SH22,5 | SH22,5 | F102 | FUSE HOLDER grid 22,5 mm, OGN0031 8201, Schurter (Buerklin) | SCHURTER | 0031.8201 | 1162740 | 96F8317 | 6
1 | UF4003 | UF4003 | DO41-10 | D107 | DIODE |  |  |  |  | 0

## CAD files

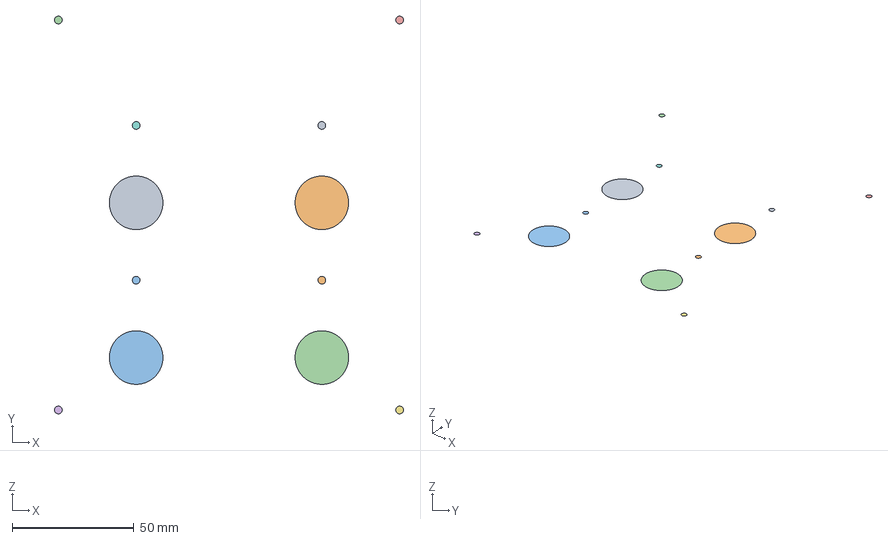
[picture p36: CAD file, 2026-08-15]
PCB/CAD/Stereo.FCStd
143.2 x 163.2 x 0 mm
Circle009
Circle010
Circle011
Circle012
Circle002
Circle003
Circle004
Circle005
Circle006
Circle008
Circle007
Circle

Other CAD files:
legacy-84-mono-inverted/Freecad/legacy-84-mono.FCStd
legacy-84-stereo/freecad/legacy-84-stereo.FCStd

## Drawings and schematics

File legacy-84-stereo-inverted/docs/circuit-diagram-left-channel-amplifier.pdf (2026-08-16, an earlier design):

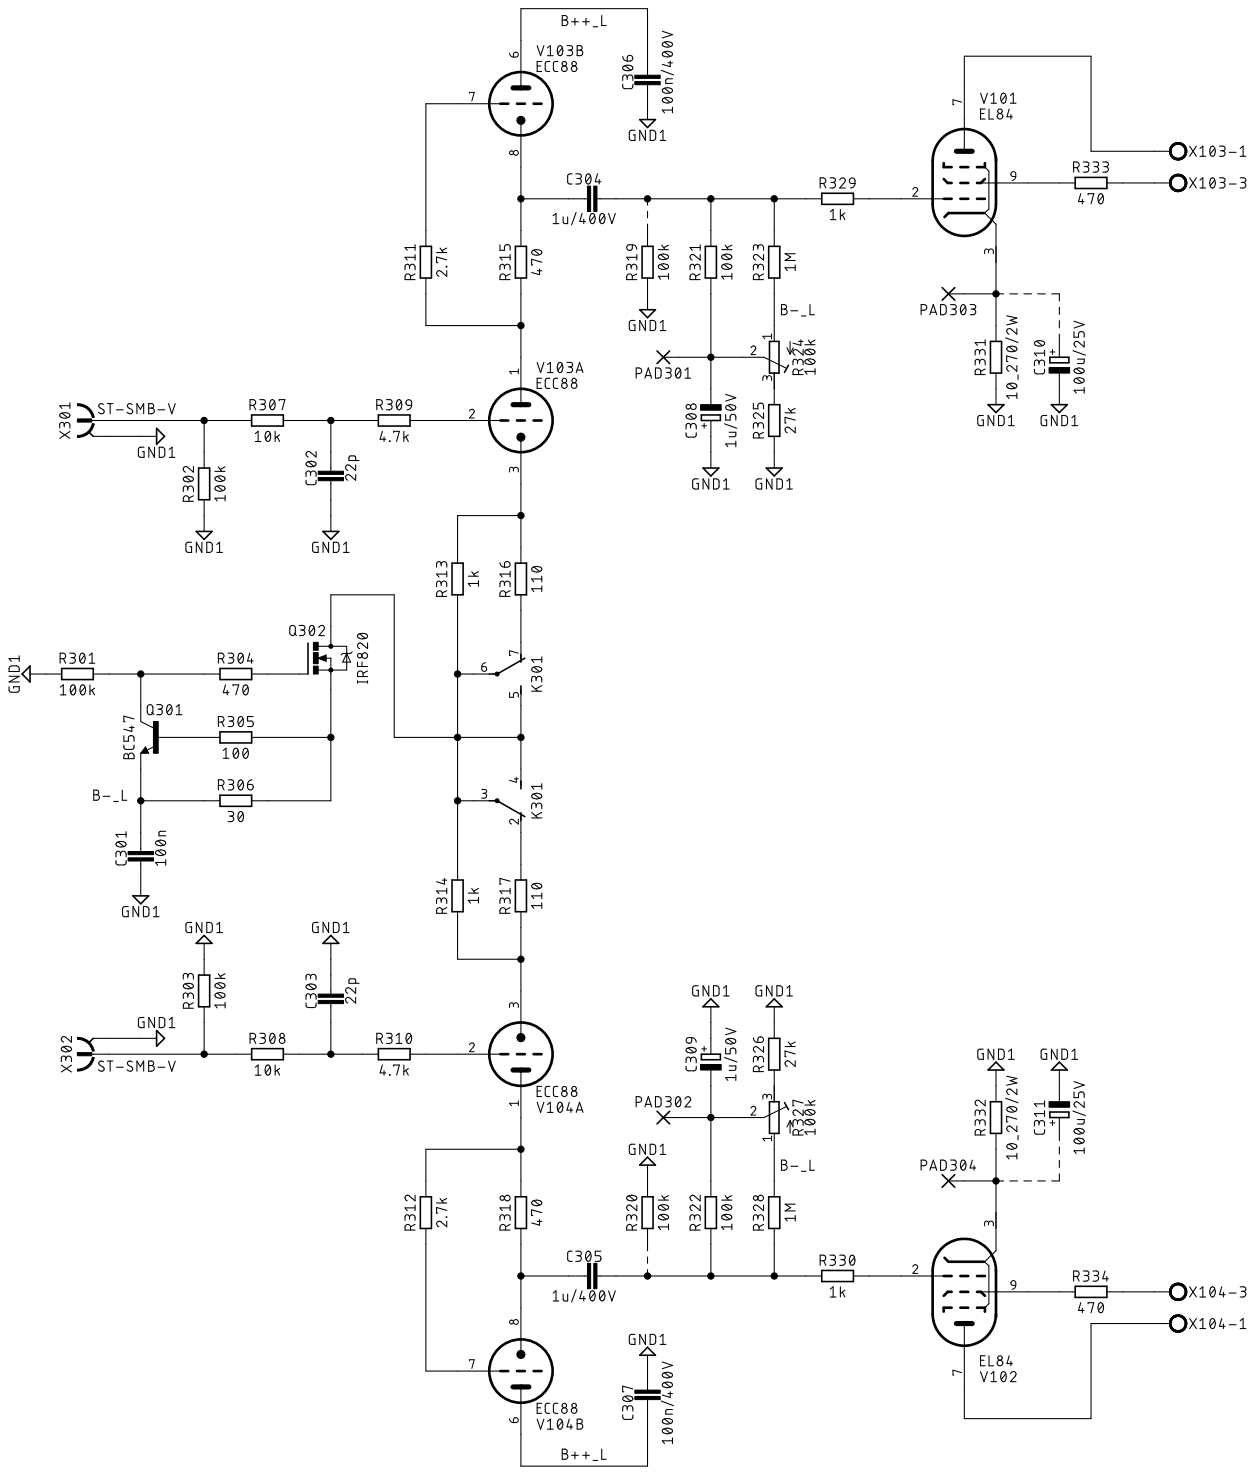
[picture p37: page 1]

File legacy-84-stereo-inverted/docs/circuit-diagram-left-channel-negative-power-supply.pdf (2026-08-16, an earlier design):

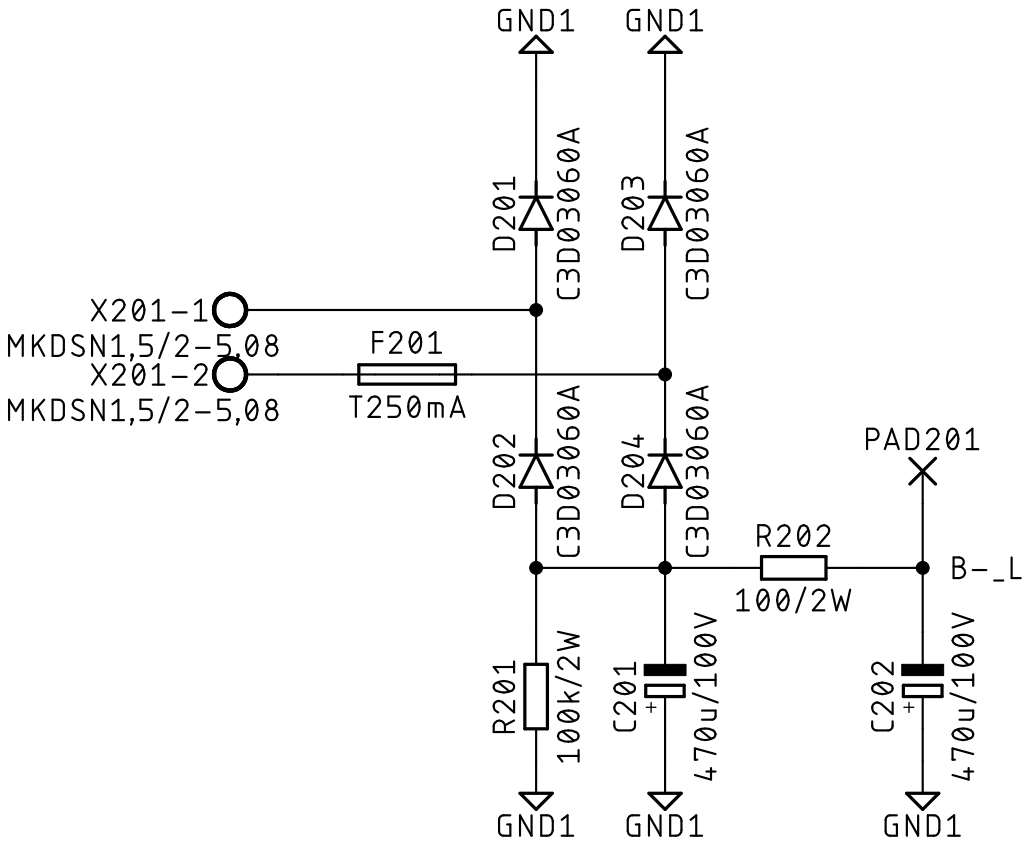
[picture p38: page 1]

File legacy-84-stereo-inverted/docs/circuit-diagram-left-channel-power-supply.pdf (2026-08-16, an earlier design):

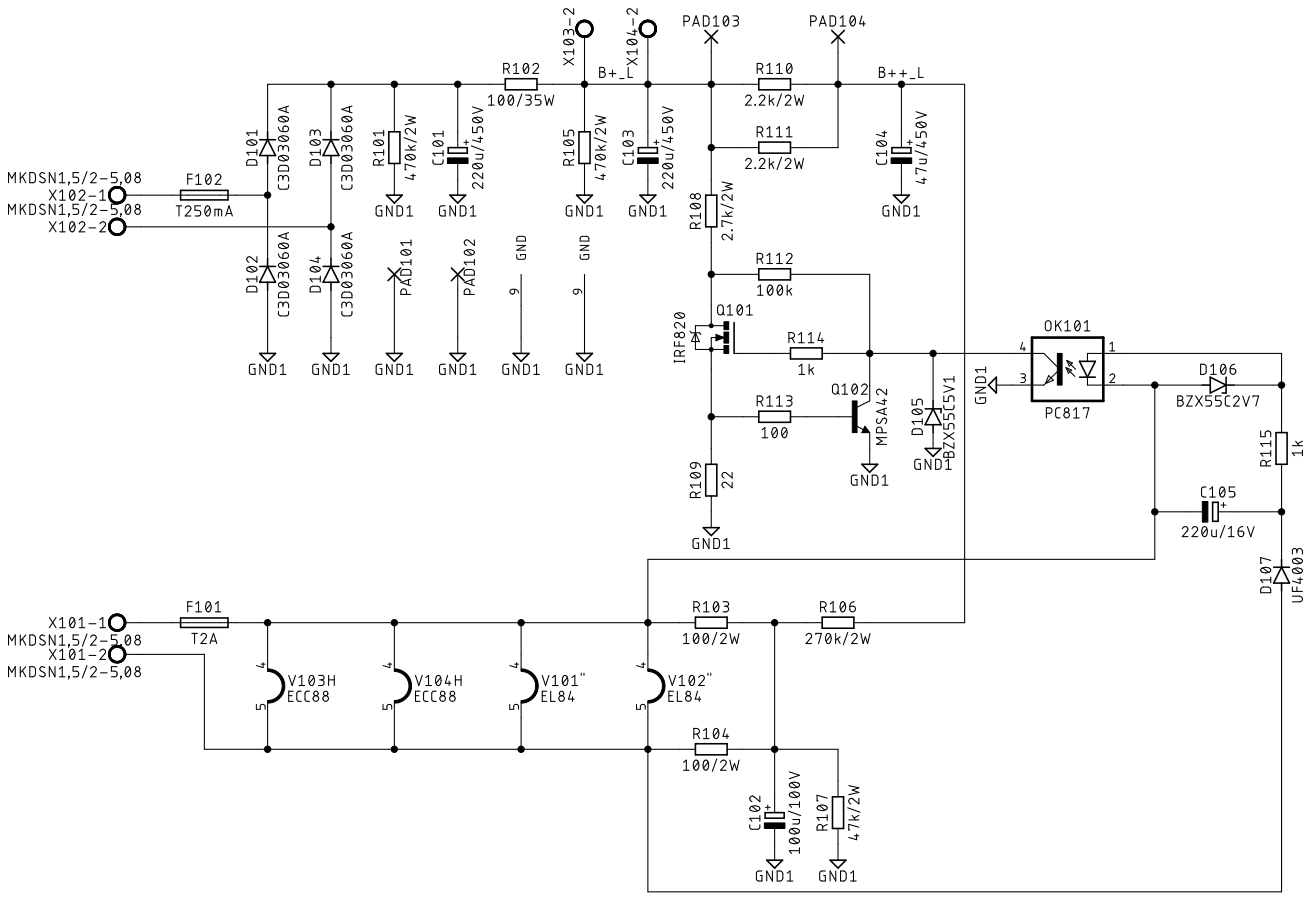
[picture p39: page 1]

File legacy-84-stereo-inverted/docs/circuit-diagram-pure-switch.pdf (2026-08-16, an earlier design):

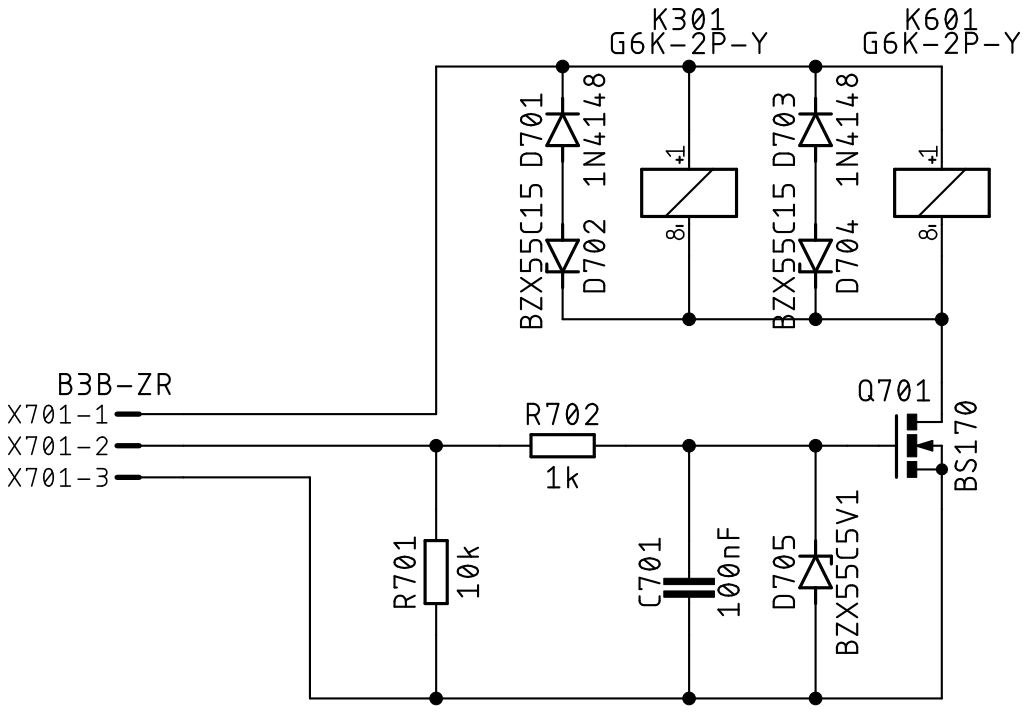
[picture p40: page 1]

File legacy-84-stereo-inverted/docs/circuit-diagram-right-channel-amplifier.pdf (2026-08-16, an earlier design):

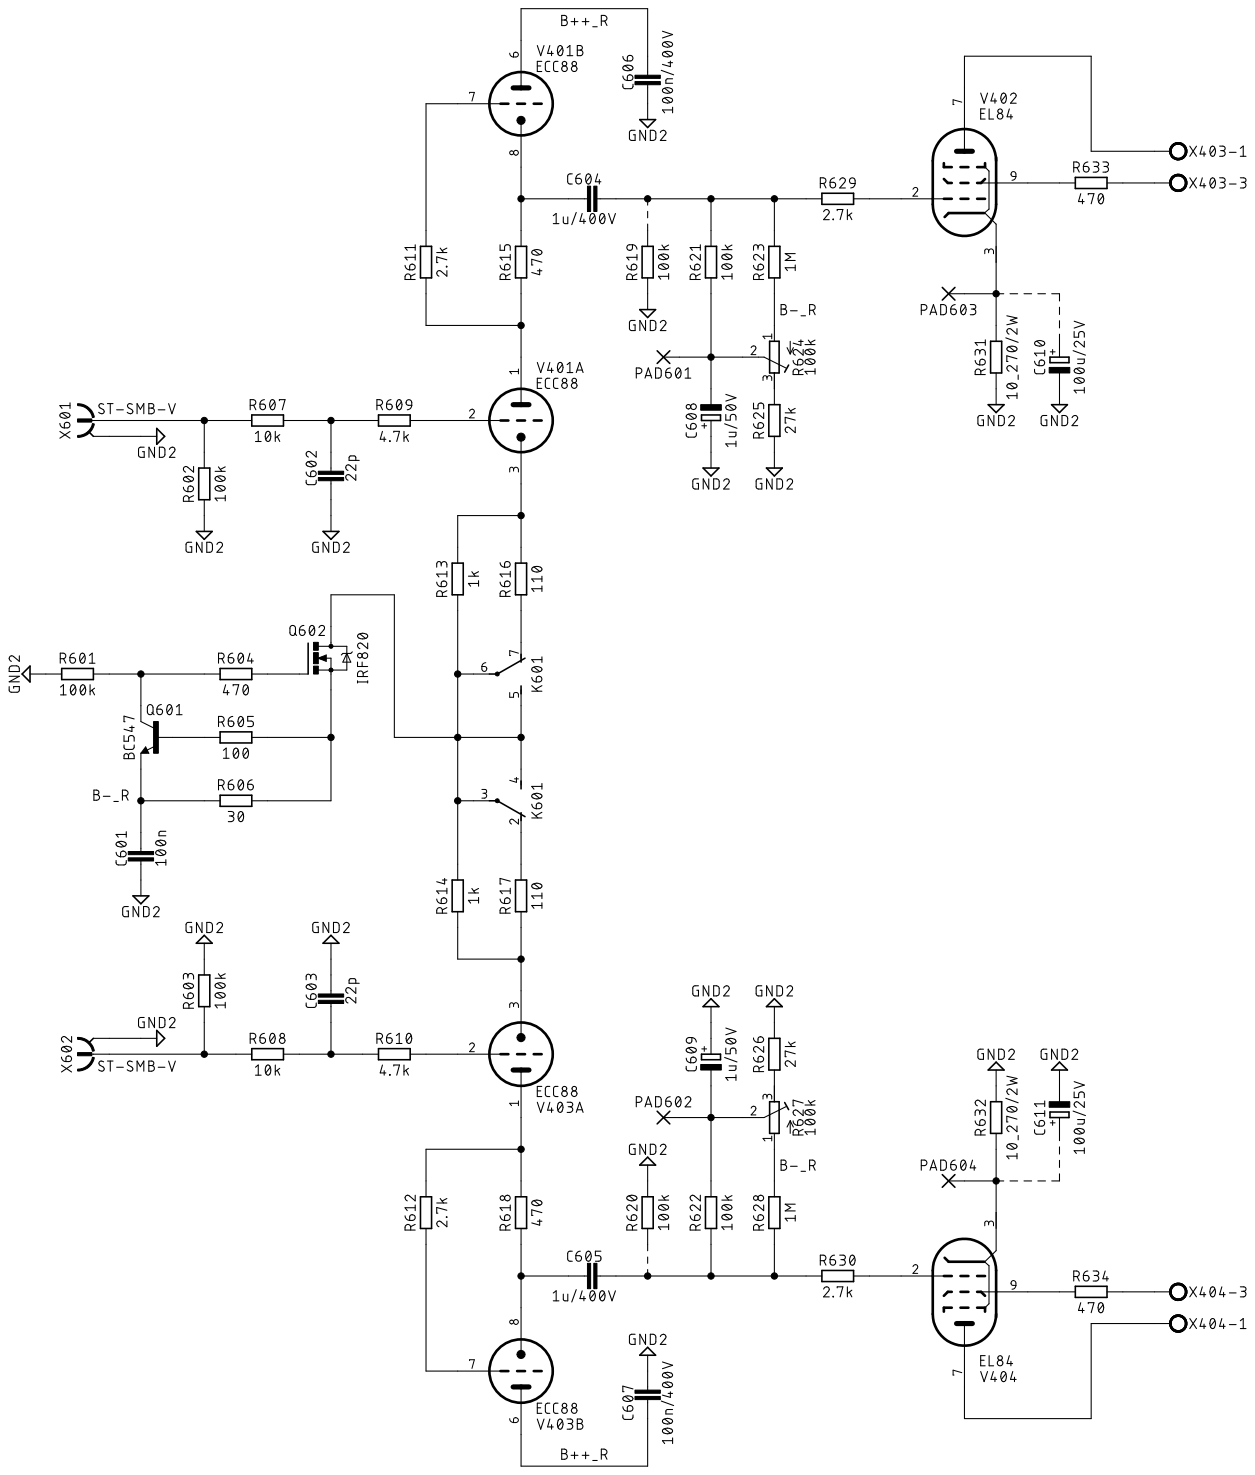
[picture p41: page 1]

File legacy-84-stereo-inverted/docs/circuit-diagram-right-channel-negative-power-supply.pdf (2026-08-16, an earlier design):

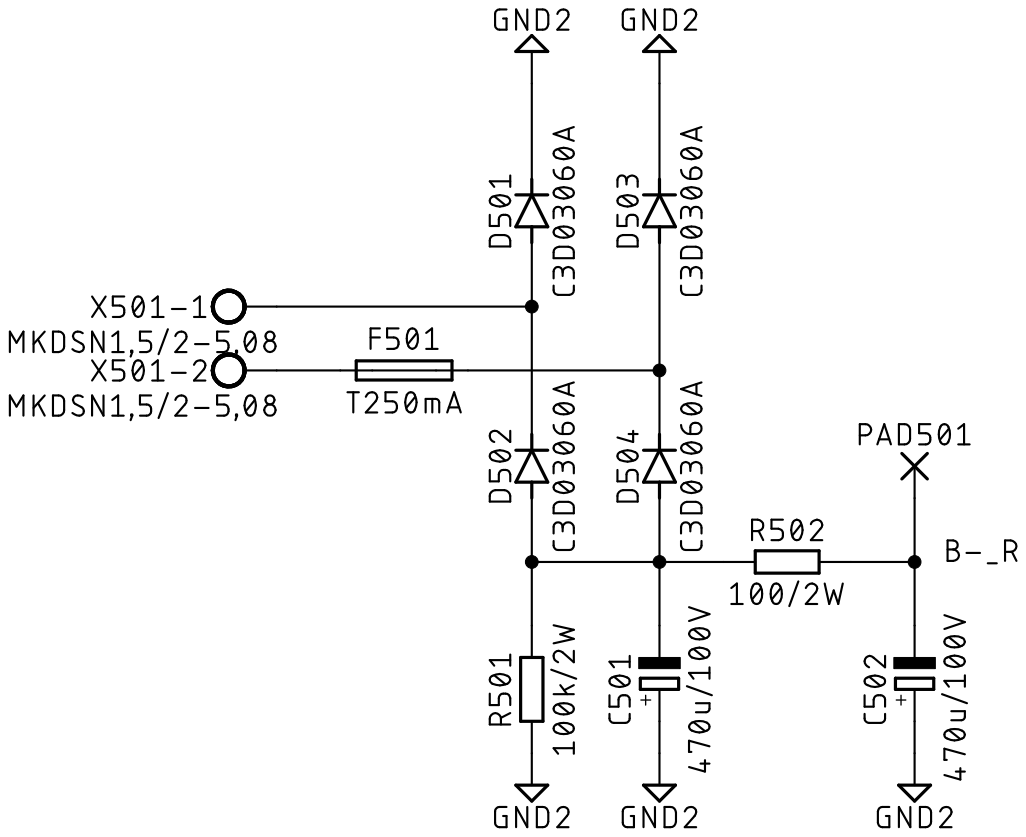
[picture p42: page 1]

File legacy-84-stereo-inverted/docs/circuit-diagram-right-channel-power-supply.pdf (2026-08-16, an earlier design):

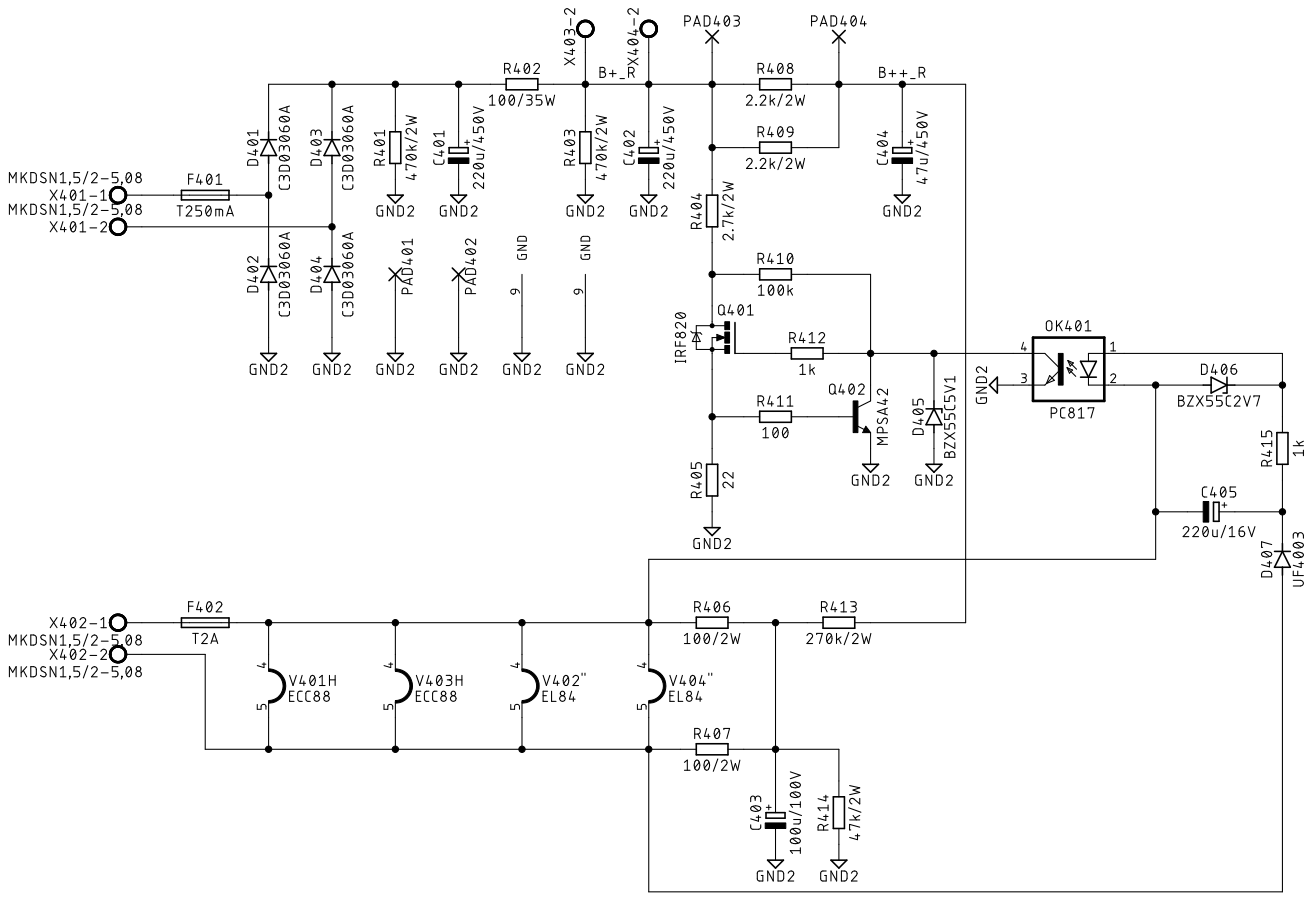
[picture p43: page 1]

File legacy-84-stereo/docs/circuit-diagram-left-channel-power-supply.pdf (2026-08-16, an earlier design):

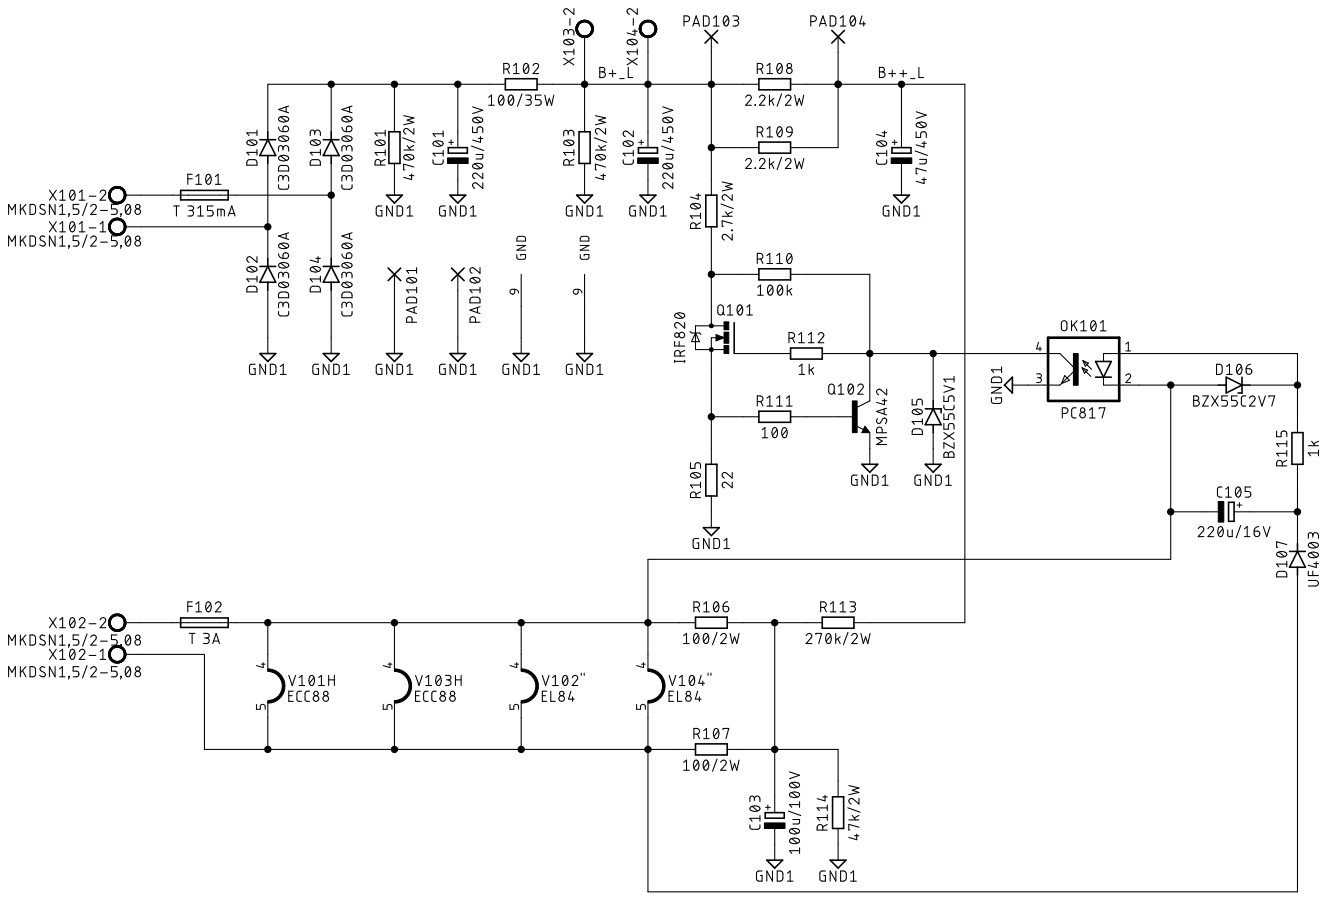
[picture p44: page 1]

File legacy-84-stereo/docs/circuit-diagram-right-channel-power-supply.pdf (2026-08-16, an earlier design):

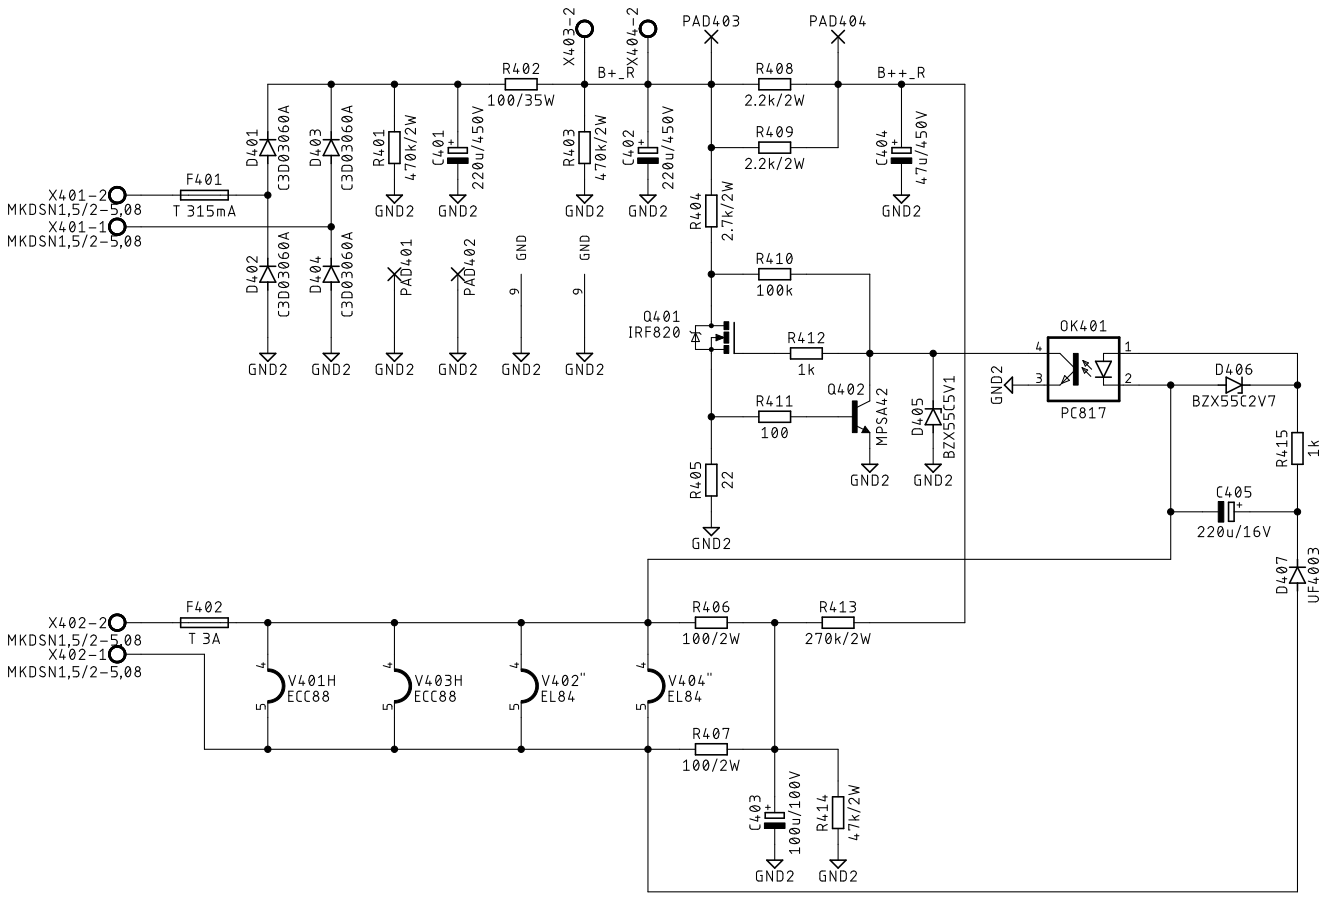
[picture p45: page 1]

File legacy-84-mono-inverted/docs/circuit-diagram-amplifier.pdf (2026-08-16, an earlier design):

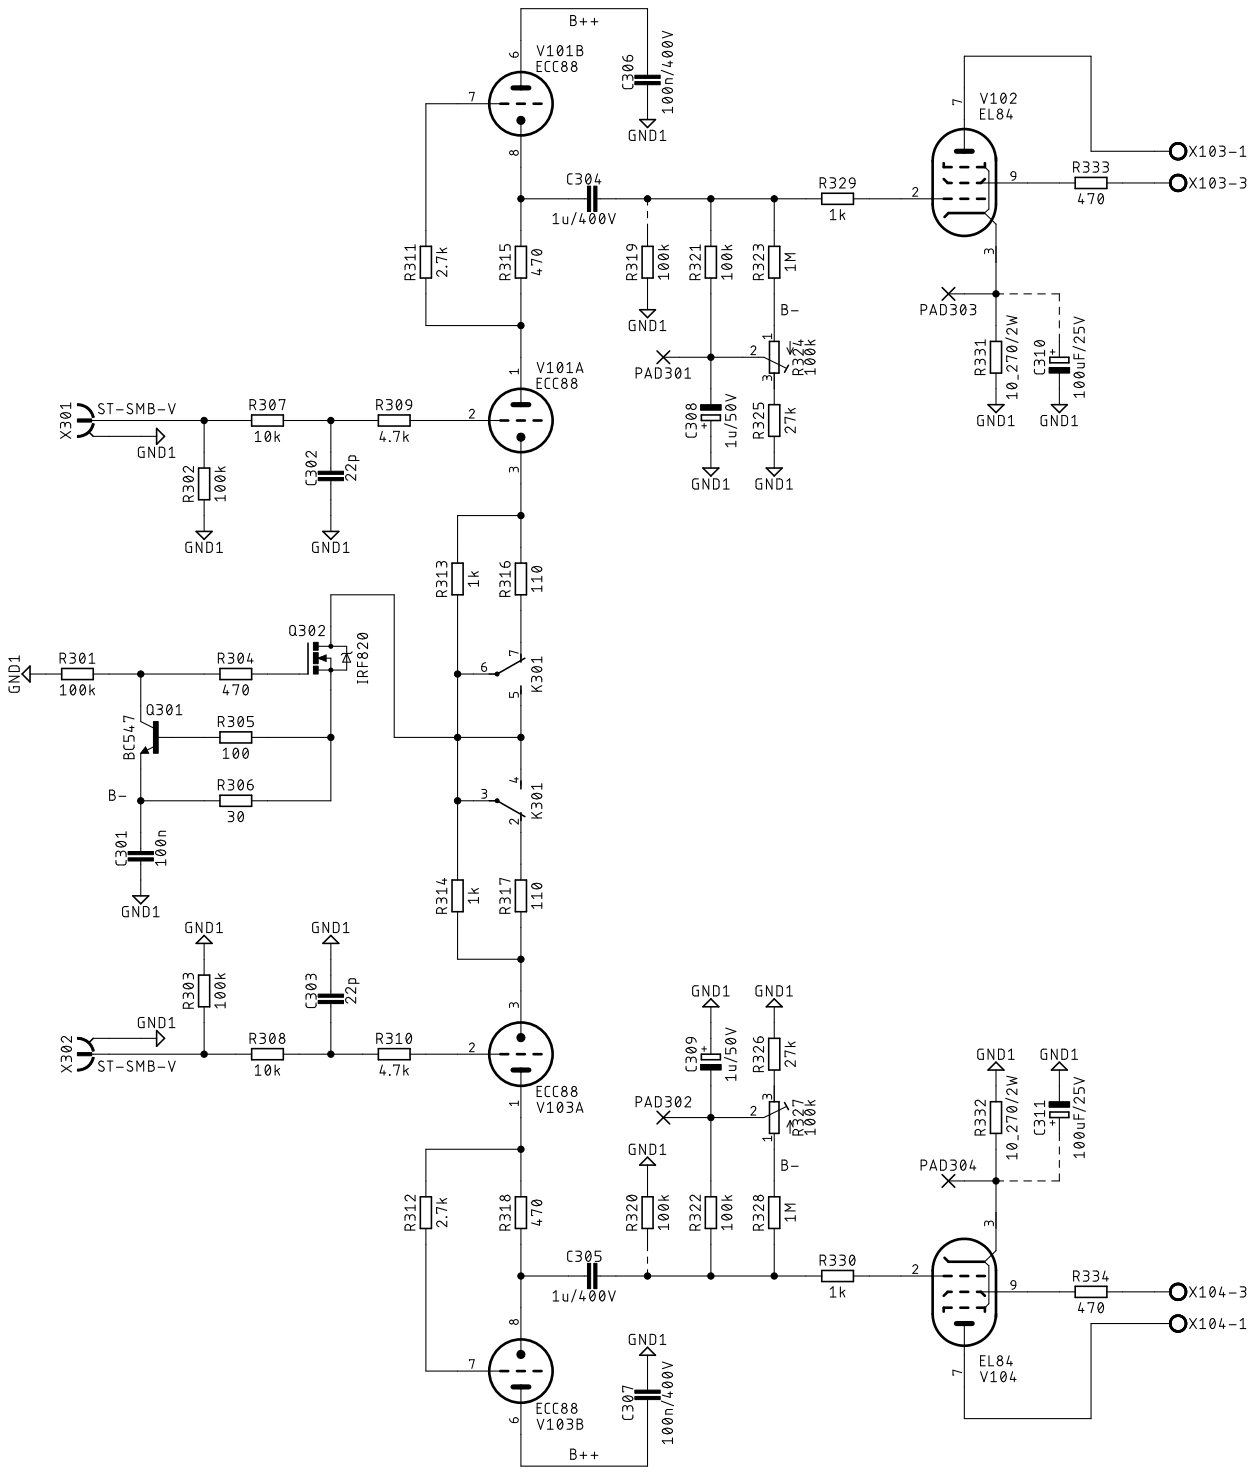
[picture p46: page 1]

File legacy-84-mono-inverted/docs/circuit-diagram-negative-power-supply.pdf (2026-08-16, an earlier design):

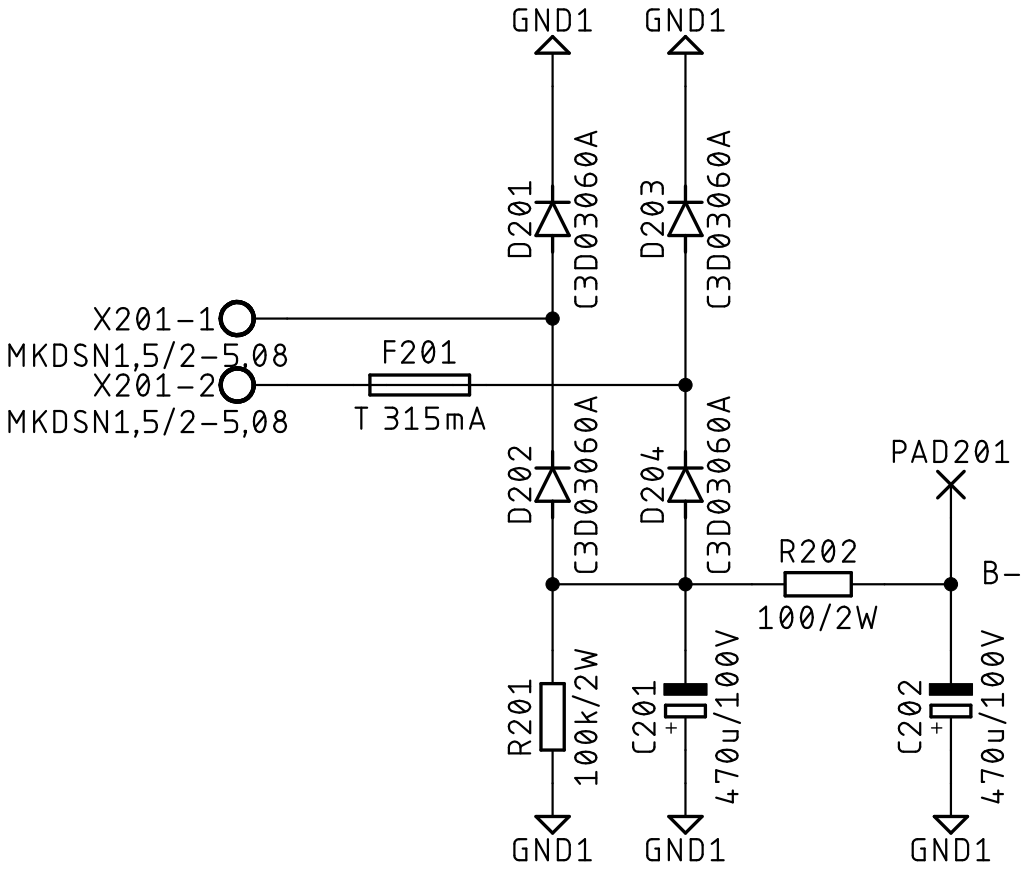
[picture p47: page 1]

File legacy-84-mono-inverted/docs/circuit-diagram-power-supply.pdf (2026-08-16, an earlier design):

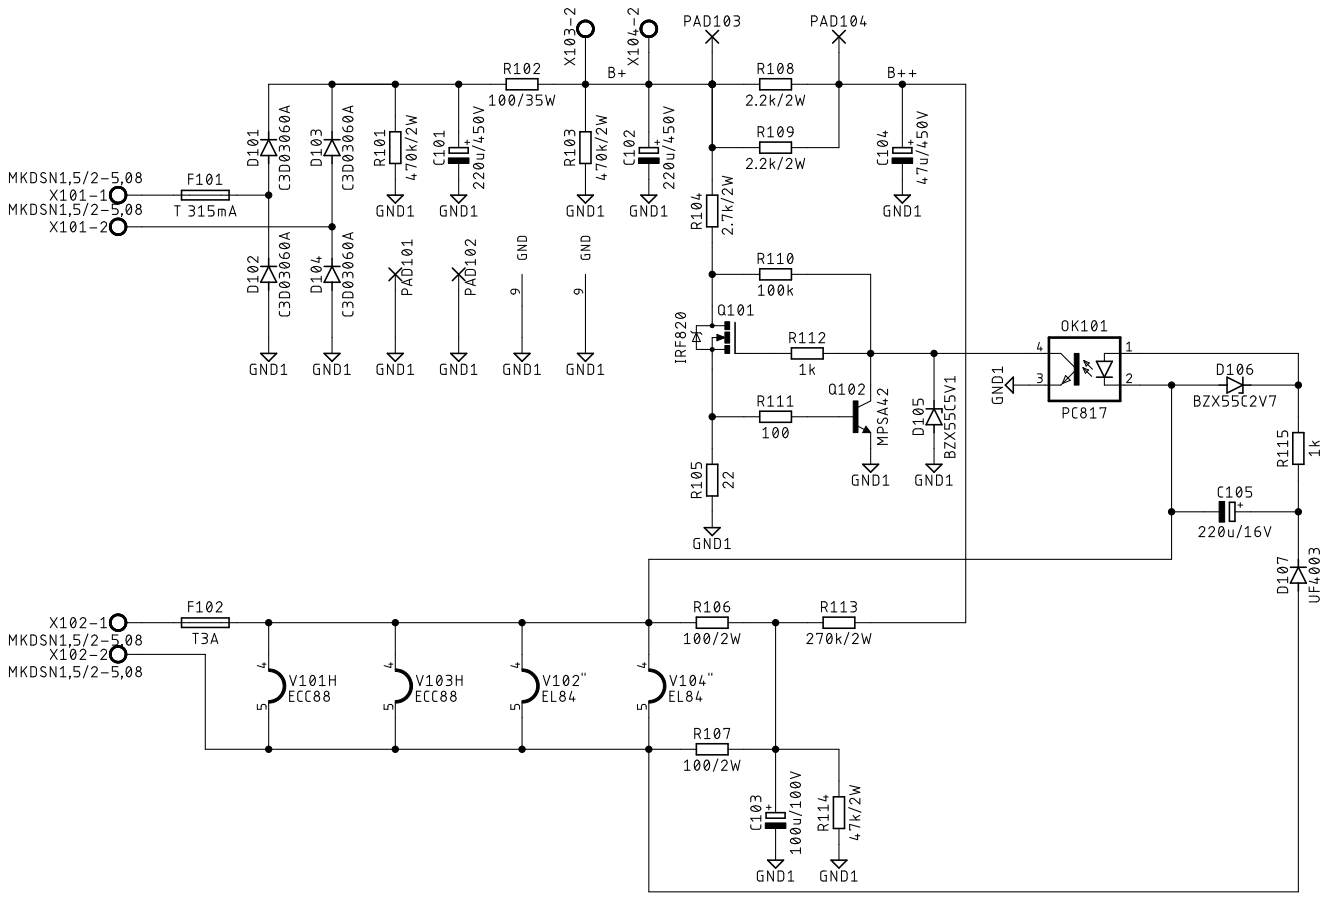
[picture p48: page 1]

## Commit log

2026-08-15 Updated and moved documentation
    [legacy-84-stereo.FCStd]
2026-08-15 Updated PCB image
2026-08-15 Updated documentation
    [Stereo.FCStd, legacy-84-mono.FCStd]
2026-08-15 Updated circuit diagrams
2026-08-16 Added PCB images
2026-08-16 Updated PCB renders
2026-08-16 Added BOMs
    [legacy-84-mono-inverted.csv, legacy-84-mono.csv, legacy-84-stereo-inverted.csv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]
2026-08-16 Added BOM comparison
2026-09-09 Added ground posts with cavities, rounded corners for large milling surfaces, updated hole dimensions, added caveties for IO boards
2026-09-13 Added ground post, added a cavity for the flat cable connector and updated other cavities
2026-09-13 Updated rear panels: Added mounting holes for standby psu, added ground posts, updated speaker terminals and updated the holes for the EIC socket and the fuse holder.
2026-09-13 Added ground connection, increased hole size for feet to 5mm and removed non-required holes
2026-09-13 Added caveties to align the tube sockets with the top of the panel
2026-09-13 Moved ground position
2026-09-13 Moved ground connection
2026-09-13 Increased radius for edges to 1.5mm
2026-09-13 Updated screenshots for Slimline enclosures
2026-09-14 Updated documentation for mono amplifier enclosures
2026-09-14 Updated documentation for Galaxy 2U enclosures
2026-09-24 Updated documentation and added all GX383 chassis options
2026-09-24 ci: update chassis download links [skip ci]
2026-09-24 Moved ground post in front panel to simplify machining
2026-09-24 Moved ground post to center of the panel
